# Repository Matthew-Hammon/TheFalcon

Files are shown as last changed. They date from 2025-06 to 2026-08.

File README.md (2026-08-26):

# The Falcon

This is a project that was inspired by ZSA's Moonlander and Voyager split keyboards. I loved how they looked and with my move to a keyboard-driven workflow, I decided that I needed to make the move. I started second-guessing myself when I saw the price, as I was a student, and I came to the realisation that I had the skills to design one.

## Features
* 36 keys per split
* Serial communication between keyboards
* USB2.0 with USB-C connectors
* Voltage protection for hot plugging
* 4 layer PCB
* RGB lighting (see the note)
* QMK compatible
* Compatible with both [Gateron Low Profile 2.0](https://www.gateron.co/products/gateron-low-profile-mechanical-switch-set) (KS-33) and [Gateron G Pro switches](https://www.gateron.co/products/gateron-switch-set)

> [!NOTE]
> I have not been able to get the RGB lighting to work. I have checked the PCB schematic and nothing stands out as the error but I could be wrong. I believe that the problem comes down to the firmware implementation and drivers.

### PCB
The PCB folder contains files for the left and right PCBs separately as well as a panelised version that combines them. The PCBs were designed by me with inspiration from other similar projects. Although four layers increase the production cost, they were intentionally kept to ensure proper signal integrity and return paths, especially due to the fast switching of multiple lines for RGB, PWM and the USB differential pair.

### Case
The SolidWorks folder contains all of the CAD files that I made for the case/switch panel. 
The folders ending with _Threaded are for the initial case designs when I had initial ideas of having the case CNCed. They have threaded pillars used for screwing the bottom plate into the top, with the top also housing the keyboard switches. 
The folders with _ScrewHoles contain a full CAD design for the case, with a bottom case being used along with M2.5 screws and hex standoffs to attach to the switch panel. The switch panel was made using FR-4 and placed alongside the PCB order. Two versions of this were made, one for 'normal' switches and an adjusted one for low-profile switches.

### Parts
All of the parts can be found in the PartsList.xlsx file. The file is detailed and most of the parts have links to places I sourced them from at the time.
A bill of materials for the panel is found as 'bom.xlsx' with the parts positions in 'pos.xlsx'. These were formatted for JLCPCB and at the time they worked. I take no responsibility for anyone who uses them along with the panel for production and I HIGHLY encourage anyone using the files to double-check everything.

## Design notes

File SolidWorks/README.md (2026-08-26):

This folder contains the Switch plate for the left and right keyboards.

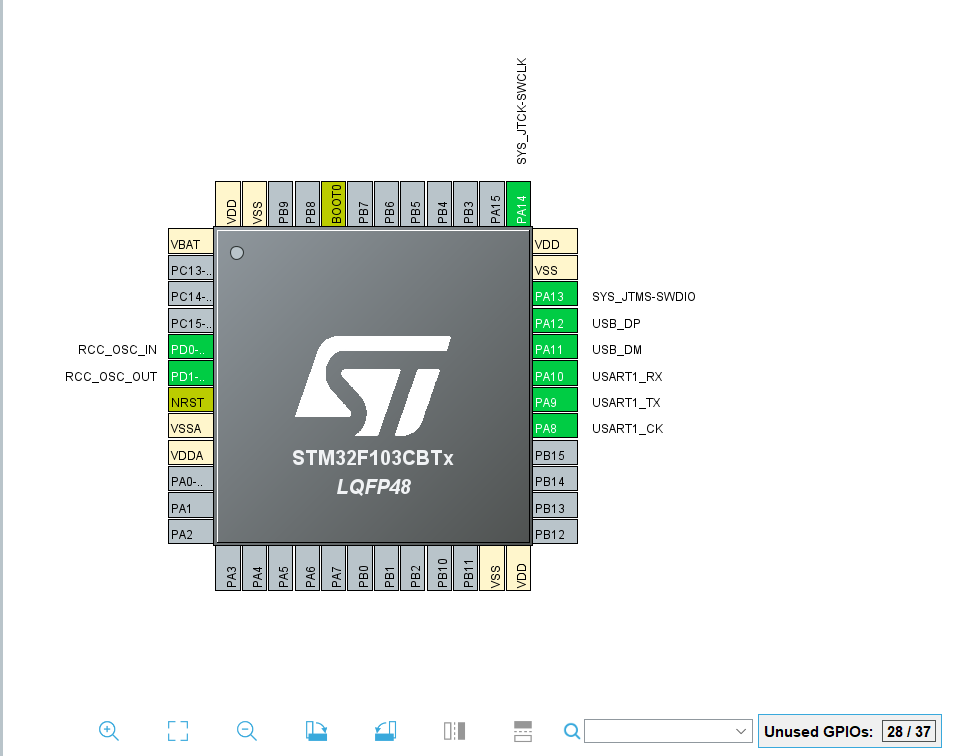
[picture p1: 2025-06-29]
MCU_Pinout.png

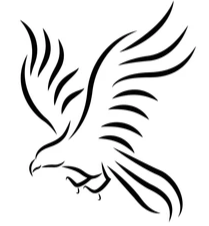
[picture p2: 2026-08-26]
Falcon.png

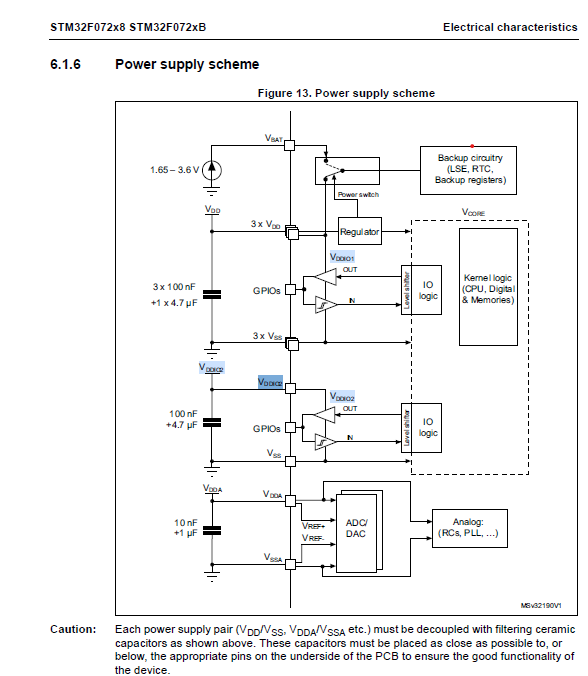
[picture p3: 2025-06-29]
PowerSupplyDecap.png

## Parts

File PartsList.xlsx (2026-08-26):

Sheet: Sheet1
Name | # | Total Number Needed | N/A | Price per unit ($) | Price per unit (R) | Total price for one PCB | Price per double unit | Total price for x units | <- Filtered | Total Price | Filtered Price | Include | Field | Number | Notes
Capacitors | 16 | 160 |  |  | 0.00 | R 0.00 | R 0.00 | R 0.00 | R 0.00 | R 0.00 | R 0.00 | TRUE | Number of PCBS | 5
Diode | 38 | 380 |  |  | 0.00 | R 0.00 | R 0.00 | R 0.00 | R 0.00 | R 0.00 | R 0.00 | TRUE | Number of Units | 3
Resistors | 24 | 240 |  |  | 0.00 | R 0.00 | R 0.00 | R 0.00 | R 0.00 | R 0.00 | R 0.00 | TRUE
FerriteBead | 2 | 20 |  |  | 0.00 | R 0.00 | R 0.00 | R 0.00 | R 0.00 | R 0.00 | R 0.00 | TRUE
RGB Leds | 38 | 380 |  | 0.26 | 4.63 | R 176.06 | R 352.12 | R 1056.37 | R 0.00 | R 1760.62 | R 0.00 | FALSE |  |  | NOT ON JLCPCB
Switches | 38 | 380 |  |  | 0.00 | R 0.00 | R 0.00 | R 0.00 | R 0.00 | R 0.00 | R 0.00 | TRUE
Push Buttons | 3 | 30 |  |  | 0.00 | R 0.00 | R 0.00 | R 0.00 | R 0.00 | R 0.00 | R 0.00 | TRUE
Electrical Switch | 1 | 10 |  |  | 0.00 | R 0.00 | R 0.00 | R 0.00 | R 0.00 | R 0.00 | R 0.00 | TRUE
MCU | 1 | 10 |  | 1.7565 | 31.30 | R 31.30 | R 62.60 | R 187.80 | R 187.80 | R 313.01 | R 313.01 | TRUE
LED Driver | 1 | 10 |  | 0.951 | 16.95 | R 16.95 | R 33.89 | R 101.68 | R 101.68 | R 169.47 | R 169.47 | TRUE
ESD Protection | 2 | 20 |  | 0.0602 | 1.07 | R 2.15 | R 4.29 | R 12.87 | R 12.87 | R 21.46 | R 21.46 | TRUE
Level Converter | 1 | 10 |  | 0.1704 | 3.04 | R 3.04 | R 6.07 | R 18.22 | R 18.22 | R 30.37 | R 30.37 | TRUE
USB Receptical | 2 | 20 |  | 0.0786 | 1.40 | R 2.80 | R 5.60 | R 16.81 | R 16.81 | R 28.01 | R 28.01 | TRUE
Crystal Oscillator | 1 | 10 |  | 0.0665 | 1.19 | R 1.19 | R 2.37 | R 7.11 | R 7.11 | R 11.85 | R 11.85 | TRUE
Total |  |  |  |  |  | R 233.48 | R 466.96 | R 1400.87 | R 344.50 | R 2334.78 | R 574.16
 |  |  |  |  |  |  |  | Price for the
Name | # per single board
Capacitors | 16
Diode | 38
Resistors | 24 | Total Number Needed | Bulk Order | Total Price Bulk Order ($) | Total Price Bulk Order (R) | Total Price
FerriteBead | 2 | 160 |  |  | R 0.00 | R 0.00
RGB Leds | 38 | 380 |  |  | R 0.00 | R 0.00
Switches | 38 | 240 |  |  | R 0.00 | R 0.00
Push Buttons | 3 | 20 |  |  | R 0.00 | R 0.00
Electrical Switch | 1 | 380 | 380.00 | 0.26 | R 4.63 | R 1760.62 |  | NOT ON JLCPCB
MCU | 1 | 380 |  |  | R 0.00 | R 0.00
LED Driver | 1 | 30 |  |  | R 0.00 | R 0.00
ESD Protection | 2 | 10 |  |  | R 0.00 | R 0.00
Level Converter | 1 | 10 | 10.00 | 1.4985 | R 26.70 | R 267.03
USB Receptical | 2 | 10 | 10.00 | 0.795 | R 14.17 | R 141.67
Crystal Oscillator | 1 | 20 | 20.00 | 0.0602 | R 1.07 | R 21.46
 |  | 10 | 10.00 | 0.1704 | R 3.04 | R 30.37
Total |  | 20 | 20.00 | 0.0786 | R 1.40 | R 28.01
 |  | 10 | 10.00 | 0.0665 | R 1.19 | R 11.85
 |  |  |  |  | R 52.20 | R 2261.00

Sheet: Sheet2
Name | # per single board | # per unit | x units | 5 units | Price per component ($) | Price per component (R) | Price per board | Price per unit | Price per x units | Price per 5 units | Include | Fields |  |  | Notes
Capacitors | 16 | 32 | 96 | 160 | 0.1 | 1.786 | R 28.58 | R 57.15 | R 171.46 | R 285.76 | TRUE | x | 3 | X | Just assumed the same prices for all caps, diodes, resistors
Diode | 38 | 76 | 228 | 380 |  | 0 | R 0.00 | R 0.00 | R 0.00 | R 0.00 | TRUE |  |  | X
Resistors | 24 | 48 | 144 | 240 | 0.0022 | 0.039292 | R 0.94 | R 1.89 | R 5.66 | R 9.43 | TRUE |  |  | X
FerriteBead | 2 | 4 | 12 | 20 | 0.2 | 3.572 | R 7.14 | R 14.29 | R 42.86 | R 71.44 | TRUE |  |  | X
RGB Leds | 38 | 76 | 228 | 380 | 0.26 | 4.6436 | R 0.00 | R 0.00 | R 0.00 | R 0.00 | FALSE |  |  |  | Not on JLC PCB
Switches | 38 | 76 | 228 | 380 |  | 0 | R 0.00 | R 0.00 | R 0.00 | R 0.00 | TRUE
Push Buttons | 3 | 6 | 18 | 30 |  | 0 | R 0.00 | R 0.00 | R 0.00 | R 0.00 | TRUE
Electrical Switch | 1 | 2 | 6 | 10 |  | 0 | R 0.00 | R 0.00 | R 0.00 | R 0.00 | TRUE
MCU | 1 | 2 | 6 | 10 | 1.7565 | 31.37109 | R 31.37 | R 62.74 | R 188.23 | R 313.71 | TRUE
LED Driver | 1 | 2 | 6 | 10 | 0.951 | 16.98486 | R 16.98 | R 33.97 | R 101.91 | R 169.85 | TRUE
ESD Protection | 2 | 4 | 12 | 20 | 0.0602 | 1.075172 | R 2.15 | R 4.30 | R 12.90 | R 21.50 | TRUE
Level Converter | 1 | 2 | 6 | 10 | 0.1704 | 3.043344 | R 3.04 | R 6.09 | R 18.26 | R 30.43 | TRUE
USB Receptical | 2 | 4 | 12 | 20 | 0.0786 | 1.403796 | R 2.81 | R 5.62 | R 16.85 | R 28.08 | TRUE
Crystal Oscillator | 1 | 2 | 6 | 10 | 0.0665 | 1.18769 | R 1.19 | R 2.38 | R 7.13 | R 11.88 | TRUE
Connectors | 2 | 4 | 12 | 20 |  | 0 | R 0.00 | R 0.00 | R 0.00 | R 0.00
Total |  |  |  |  |  |  | R 94.21 | R 188.42 | R 565.25 | R 942.08
Name | # per single board | # per unit | x units | 5 units | Price per component ($) | Price per component (R) | Price per board | Price per unit | Price per x units | Price per 5 units | Include | Fields
Capacitors | 16 | 32 | 96 | 160 |  | 0 | R 48.00 | R 96.00 | R 288.00 | R 480.00 | TRUE | x | 3
Diode | 38 | 76 | 228 | 380 |  | 0 | R 114.00 | R 228.00 | R 684.00 | R 1140.00 | TRUE
Resistors | 24 | 48 | 144 | 240 |  | 0 | R 72.00 | R 144.00 | R 432.00 | R 720.00 | TRUE
FerriteBead | 2 | 4 | 12 | 20 |  | 0 | R 6.00 | R 12.00 | R 36.00 | R 60.00 | TRUE
RGB Leds | 38 | 76 | 228 | 380 | 0.26 | 4.6436 | R 114.00 | R 228.00 | R 684.00 | R 1140.00 | TRUE
Switches | 38 | 76 | 228 | 380 |  | 0 | R 114.00 | R 228.00 | R 684.00 | R 1140.00 | TRUE
Push Buttons | 3 | 6 | 18 | 30 |  | 0 | R 9.00 | R 18.00 | R 54.00 | R 90.00 | TRUE
Electrical Switch | 1 | 2 | 6 | 10 |  | 0 | R 3.00 | R 6.00 | R 18.00 | R 30.00 | TRUE
MCU | 1 | 2 | 6 | 10 | 1.7565 | 31.37109 | R 3.00 | R 6.00 | R 18.00 | R 30.00 | TRUE
LED Driver | 1 | 2 | 6 | 10 | 0.951 | 16.98486 | R 3.00 | R 6.00 | R 18.00 | R 30.00 | TRUE
ESD Protection | 2 | 4 | 12 | 20 | 0.0602 | 1.075172 | R 6.00 | R 12.00 | R 36.00 | R 60.00 | TRUE
Level Converter | 1 | 2 | 6 | 10 | 0.1704 | 3.043344 | R 3.00 | R 6.00 | R 18.00 | R 30.00 | TRUE
USB Receptical | 2 | 4 | 12 | 20 | 0.0786 | 1.403796 | R 6.00 | R 12.00 | R 36.00 | R 60.00 | TRUE
Crystal Oscillator | 1 | 2 | 6 | 10 | 0.0665 | 1.18769 | R 3.00 | R 6.00 | R 18.00 | R 30.00 | TRUE
Connectors
Total |  |  |  |  |  |  | R 504.00 | R 1008.00 | R 3024.00 | R 5040.00

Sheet: JLCPCB(Detailed)
Name | Value | # per single board | # per unit | x units | 5 units | Price per component ($) | Price per component (R) | Price per board | Price per unit | Price per x units | Price per 5 units | Include | Package | Fields |  | Link | Notes |  | In Order
Capacitors | 10u | 1 | 2 | 6 | 10 | 0.0087 | 0.155382 | R 0.16 | R 0.31 | R 0.93 | R 1.55 | TRUE | 0805 | x | 3 | https://jlcpcb.com/partdetail/2065-CL21A106KOQNNNE/C1713 |  |  | TRUE
 | 100n | 8 | 16 | 48 | 80 | 0.0032 | 0.057152 | R 0.46 | R 0.91 | R 2.74 | R 4.57 | TRUE | 0402 |  |  | https://jlcpcb.com/partdetail/1877-CL05B104KO5NNNC/C1525 |  |  | TRUE
 | 10n | 1 | 2 | 6 | 10 | 0.0031 | 0.055366 | R 0.06 | R 0.11 | R 0.33 | R 0.55 | TRUE | 0402 |  |  | https://jlcpcb.com/partdetail/1876-0402B103K500NT/C1524 |  |  | TRUE
 | 1u | 3 | 6 | 18 | 30 | 0.0032 | 0.057152 | R 0.17 | R 0.34 | R 1.03 | R 1.71 | TRUE | 0603 |  |  | https://jlcpcb.com/partdetail/1944-CL10A105KO8NNNC/C1592 |  |  | TRUE
 | 22u | 2 | 4 | 12 | 20 | 0.0324 | 0.578664 | R 1.16 | R 2.31 | R 6.94 | R 11.57 | TRUE | 1206 |  |  | https://jlcpcb.com/partdetail/2211-1206X226K100NT/C1859 |  |  | TRUE
 | 10p | 2 | 4 | 12 | 20 | 0.001 | 0.01786 | R 0.04 | R 0.07 | R 0.21 | R 0.36 | TRUE | 0402 |  |  | https://jlcpcb.com/partdetail/1897-0402CG100J500NT/C1545 |  |  | TRUE
 |  | 17
Resistors | 5,1k | 4 | 8 | 24 | 40 | 0.001 | 0.01786 | R 0.07 | R 0.14 | R 0.43 | R 0.71 | TRUE | 0603 |  |  | https://jlcpcb.com/partdetail/23794-0603WAF5111T5E/C23067 | 100mW |  | TRUE
 | 100k | 1 | 2 | 6 | 10 | 0.001 | 0.01786 | R 0.02 | R 0.04 | R 0.11 | R 0.18 | TRUE | 0603 |  |  | https://jlcpcb.com/partdetail/Yageo-RC0603FR07100KL/C14675 | 100mW |  | TRUE
 | 10k | 1 | 2 | 6 | 10 | 0.0008 | 0.014288 | R 0.01 | R 0.03 | R 0.09 | R 0.14 | TRUE | 0603 |  |  | https://jlcpcb.com/partdetail/16079-0603WAJ0103T5E/C15401 | 100mW |  | TRUE
 | 4k7 | 2 | 4 | 12 | 20 | 0.0011 | 0.019646 | R 0.04 | R 0.08 | R 0.24 | R 0.39 | TRUE | 0603 |  |  | https://jlcpcb.com/partdetail/23889-0603WAF4701T5E/C23162 | Maybe change to 4.7k for I2C |  | TRUE
 | 20 | 10 | 20 | 60 | 100 | 0.01 | 0.1786 | R 1.79 | R 3.57 | R 10.72 | R 17.86 | TRUE | 0603 |  |  | https://jlcpcb.com/partdetail/23677-0603WAF200JT5E/C22950 |  |  | TRUE
 | 51 | 5 | 10 | 30 | 50 | 0.01 | 0.1786 | R 0.89 | R 1.79 | R 5.36 | R 8.93 | TRUE | 0603 |  |  | https://jlcpcb.com/partdetail/18426-UNI_ROYAL0805W8F510JT5E/C17738 |  |  | TRUE
 | 1k5 | 1 | 2 | 6 | 10 | 0.01 | 0.1786 | R 0.18 | R 0.36 | R 1.07 | R 1.79 | TRUE | 0603 |  |  | https://jlcpcb.com/partdetail/23570-0603WAF1501T5E/C22843 |  |  | TRUE
 | 0 | 1 | 2 | 6 | 10 | 0.0016 | 0.028576 | R 0.03 | R 0.06 | R 0.17 | R 0.29 | TRUE | 0805 |  |  | https://jlcpcb.com/partdetail/18165-0805W8F0000T5E/C17477 |  |  | TRUE
 |  | 25
Diode | x | 38 | 76 | 228 | 380 | 0.009 | 0.16074 | R 6.11 | R 12.22 | R 36.65 | R 61.08 | TRUE | SOD-123 |  |  | https://jlcpcb.com/partdetail/2456-1N4148W/C2099 |  |  | TRUE
PWR LED | x | 1 | 2 | 6 | 10 | 0.02 | 0.3572 | R 0.36 | R 0.71 | R 2.14 | R 3.57 | TRUE | 0805 |  |  | https://jlcpcb.com/partdetail/85429-NCD0805G1/C84260 |  |  | TRUE
Fuse | 500mA | 1 | 2 | 6 | 10 | 0.0512 | 0.914432 | R 0.91 | R 1.83 | R 5.49 | R 9.14 | TRUE | 1206 |  |  | https://jlcpcb.com/partdetail/Shenzhen_JdtFuse-ASMD1206025/C135336 |  |  | TRUE
RGB Drivers | IS31FL3729 | 1 | 2 | 6 | 10 | 0.951 | 16.98486 | R 16.98 | R 33.97 | R 101.91 | R 169.85 | TRUE | QFN-32-EP(4x4) |  |  | https://jlcpcb.com/partdetail/3305932-IS31FL3729_QFLS4TR/C2940549 |  |  | TRUE
Conn | 01x04 | 2 | 4 | 12 | 20 | 0.0585 | 1.04481 | R 0.00 | R 0.00 | R 0.00 | R 0.00 | FALSE | HAVENT INCLUDED YET |  |  | https://jlcpcb.com/partdetail/XFCN-PM254V_11_04H85/C541851
 | 01x01 | 1 | 2 | 6 | 10 |  | 0 | R 0.00 | R 0.00 | R 0.00 | R 0.00 | FALSE | Just solder pad
 | 02x05 | 1 | 2 | 6 | 10 |  | 0 | R 0.00 | R 0.00 | R 0.00 | R 0.00 | TRUE |  |  |  |  | SMALLER: | https://jlcpcb.com/partdetail/Megastar-ZX_PM1_27_25PU/C7499360
RGB Leds | T36K3BGR | 38 | 76 | 228 | 380 | 0.0365 | 0.65189 | R 24.77 | R 49.54 | R 148.63 | R 247.72 | TRUE |  |  |  | https://jlcpcb.com/partdetail/Hongqiguang-T36K3BGR05D000121U1930/C5184580 | Not on JLC PCB |  | FALSE
Gateron Switches | x | 38 | 76 | 228 | 380 |  | 0 | R 0.00 | R 0.00 | R 0.00 | R 0.00 | FALSE |  |  |  |  |  |  | TRUE
Push Button | x | 2 | 4 | 12 | 20 | 0.15 | 2.679 | R 5.36 | R 10.72 | R 32.15 | R 53.58 | TRUE | SMD,2.5x3mm |  |  | https://jlcpcb.com/partdetail/OmronElectronics-B3U1000P/C231329 |  |  | TRUE
STM32 | x | 1 | 2 | 6 | 10 | 3.1725 | 56.66085 | R 56.66 | R 113.32 | R 339.97 | R 566.61 | TRUE |  |  |  | https://jlcpcb.com/partdetail/Stmicroelectronics-STM32G431CBT6/C529355 |  |  | TRUE
USB Connector | x | 2 | 4 | 12 | 20 | 0.0786 | 1.403796 | R 2.81 | R 5.62 | R 16.85 | R 28.08 | TRUE |  |  |  | https://jlcpcb.com/partdetail/gswitch-GT_USB7010ASV/C2988369 |  |  | TRUE
Level Converter | x | 1 | 2 | 6 | 10 | 0.1704 | 3.043344 | R 3.04 | R 6.09 | R 18.26 | R 30.43 | TRUE |  |  |  | https://jlcpcb.com/partdetail/Advanced_MonolithicSystems-AMS1117_33/C6186 |  |  | TRUE
ESD Converter | USBLC6-2P6 | 2 | 4 | 12 | 20 | 0.0602 | 1.075172 | R 2.15 | R 4.30 | R 12.90 | R 21.50 | TRUE |  |  |  | https://jlcpcb.com/partdetail/31512546-USBLC6_2P6_UMW/C29780639 |  |  | TRUE
Crystal Oscillator | x | 1 | 2 | 6 | 10 | 0.0665 | 1.18769 | R 1.19 | R 2.38 | R 7.13 | R 11.88 | TRUE |  |  |  | https://jlcpcb.com/partdetail/Yxc_CrystalOscillators-X322516MOB4SI/C12668 |  |  | TRUE
Mounting Hole | x | 6 | 12 | 36 | 60 |  | 0 | R 0.00 | R 0.00 | R 0.00 | R 0.00 | TRUE
Switch Socket |  | 0 | 0 | 0 | 0 | 0.1342777778 | 2.398201111 | R 0.00 | R 0.00 | R 0.00 | R 0.00 | FALSE
DIP Switch | 2 pin | 0 | 0 | 0 | 0 | 0.2513 | 4.488218 | R 0.00 | R 0.00 | R 0.00 | R 0.00 | TRUE |  |  |  | https://jlcpcb.com/partdetail/41719-DSHP02TSGET/C40735 |  |  | FALSE
 |  | 178 |  |  |  |  |  | R 125.41 | R 250.81 | R 752.43 | R 1254.06
M2.5 Standoff | https://www.digikey.co.za/en/products/detail/würth-elektronik/970080144/9488538 |  |  |  |  |  |  |  |  | https://za.rs-online.com/web/p/standoffs/2053013?gb=s
Gaskets | https://za.rs-online.com/web/p/foam-tapes/0567963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
NEED TO DO CONNECTORS
M2 Standoff | https://za.rs-online.com/web/p/standoffs/2240361?gb=s
M2 Screw | https://www.robotics.org.za/M2-L8-KIT
Rubber feet | https://za.rs-online.com/web/p/anti-slip-pads/1735972
PCB | 2 LAYER
 | 4 LAYER | 900
Final
M2.5x5mm Standoff | https://za.rs-online.com/web/p/standoffs/2052903 |  |  |  |  |  | R 9.58 |  | 15
M2.5x8mm Standoff | https://za.rs-online.com/web/p/standoffs/2052905?gb=s |  |  |  |  |  | R 11.04 |  | 30 | R 331.23
M2.5 Screw | https://za.rs-online.com/web/p/machine-screws/9141630?gb=s |  |  |  |  |  | R 0.98 |  | 100 | R 97.70
M2.5 Insert |  |  |  |  |  |  |  |  |  | R 0.00
Rubber feet | https://za.rs-online.com/web/p/anti-slip-pads/1735972 |  |  |  |  |  | R 273.99 | Set - 150 | 1 | R 273.99 |  |  | https://www.digikey.co.za/en/products/detail/3m/SJ5302/2345107
Gasket | https://za.rs-online.com/web/p/foam-tapes/0567963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 |  |  |  |  |  | 157.58 | Set | 1 | R 157.58
Foam Layer | https://za.rs-online.com/web/p/foam-inserts/1368892?gb=s |  |  |  |  |  | 76.98 |  | 2 | R 153.96
RGB Leds | https://www.digikey.co.za/en/products/detail/harvatek-corporation/T36K3BGR-05D000121U1930/13588739
 |  |  |  |  |  |  |  |  |  | R 1014.46

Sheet: Sheet3
 | Cost per unit
PCB | R 560.00
Switch layer | R 100.00
RGB Leds | R 330.00
Switches |  | Approx, depends on switch
Key caps |  | Estimated but depends
Screws and mounts | R 150.00
Feet | R 23.00
 | R 1163.00

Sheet: Left
Comment | Designator | Footprint | LCSC Part Number | Extended | New Part Number | LCSC Part Number
10n | C6 | Capacitor_SMD:C_0402_1005Metric | C1524 | TRUE | C15195 | C15195
100n | C2,C3,C4,C5,C8,C9,C12,C14 | Capacitor_SMD:C_0402_1005Metric | C1525 | FALSE |  | C1525
10p | C15,C16 | Capacitor_SMD:C_0402_1005Metric | C1545 | TRUE | C32949 | C32949
1u | C7,C13,C17 | Capacitor_SMD:C_0603_1608Metric | C1592 | TRUE | C15849 | C15849
10u | C1 | Capacitor_SMD:C_0805_2012Metric | C1713 | TRUE | C15850 | C15850
22u | C10,C11 | Capacitor_SMD:C_1206_3216Metric | C1859 | TRUE | C12891 | C12891
Diode | D1,D2,D3,D4,D5,D6,D7,D8,D9,D10,D11,D12,D13,D14,D15,D16,D17,D18,D19,D20,D21,D22,D23,D24,D25,D26,D27,D28,D29,D30,D31,D32,D33,D36,D37,D38 | Diode_SMD:D_SOD-123 | C2099 | TRUE | C81598 | C81598
AMS1117-3.3 | U4 | Package_TO_SOT_SMD:SOT-223-3_TabPin2 | C6186 | FALSE |  | C6186
X322516MOB4SI | Y1 | SamacSys_Parts:X322516MOB4SI | C12668 | FALSE |  | C12668
100k | R5 | Resistor_SMD:R_0603_1608Metric | C14675 | TRUE | C25803 | C25803
10k | R6 | Resistor_SMD:R_0603_1608Metric | C15401 | TRUE | C25804 | C25804
51 | R11,R13,R16,R19,R22 | Resistor_SMD:R_0603_1608Metric | C17738 | FALSE |  | C17738
1k5 | R25 | Resistor_SMD:R_0603_1608Metric | C22843 | FALSE |  | C22843
20 | R9,R10,R12,R14,R15,R17,R18,R20,R21,R23 | Resistor_SMD:R_0603_1608Metric | C22950 | FALSE |  | C22950
5k1 | R1,R2,R3,R4 | Resistor_SMD:R_0603_1608Metric | C23067 | TRUE | C23186 | C23186
4k7 | R24,R33 | Resistor_SMD:R_0603_1608Metric | C23162 | FALSE |  | C23162
LED | D39 | LED_SMD:LED_0805_2012Metric | C84260 | TRUE | C84256 | C84256
500mA | F1 | Fuse:Fuse_1206_3216Metric | C135336 | TRUE | C20798 | C20798 | No Stock of 1
SW_Push | SW1,SW2 | Button_Switch_SMD:SW_SPST_B3U-1000P | C231329 | TRUE | C720477 | C720477
STM32G431CBTx | U6 | Package_QFP:LQFP-48_7x7mm_P0.5mm | C529355 | FALSE |  | C529355
IS31FL3729-QFLS4-TR | IC1 | SamacSys_Parts:QFN40P400X400X80-33N-D | C2940549 | FALSE |  | C2940549
USB_C_Receptacle_USB2.0_16P | USB1,USB2 | Connector_USB:USB_C_Receptacle_G-Switch_GT-USB-7010ASV | C2988369 | FALSE |  | C2988369
USBLC6-2P6 | U2,U3 | Package_TO_SOT_SMD:SOT-666 | C29780639 | FALSE |  | C29780639

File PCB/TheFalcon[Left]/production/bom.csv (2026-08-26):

Designator | Footprint | Quantity | Value | LCSC Part #
C1 | 0805 | 1 | 10u
C10, C11 | 1206 | 2 | 22u
C12, C14, C2, C3, C4, C5, C8, C9 | 0402 | 8 | 100n
C13, C17, C7 | 0603 | 3 | 1u
C15, C16 | 0402 | 2 | 10p
C6 | 0402 | 1 | 10n
D1, D10, D11, D12, D13, D14, D15, D16, D17, D18, D19, D2, D20, D21, D22, D23, D24, D25, D26, D27, D28, D29, D3, D30, D31, D32, D33, D36, D37, D38, D4, D5, D6, D7, D8, D9 | D_SOD-123 | 36 | Diode
D39 | 0805 | 1 | LED
F1 | 1206 | 1 | 500mA
IC1 | QFN40P400X400X80-33N-D | 1 | IS31FL3729-QFLS4-TR
J1, J3, J4, J5, J6, J7 | SolderWire-0.1sqmm_1x01_D0.4mm_OD1mm | 6 | Conn_01x01
J2 | SolderWire-1sqmm_1x04_P5.4mm_D1.4mm_OD2.7mm | 1 | Conn_01x04_Pin
R1, R2, R3, R4 | 0603 | 4 | 5k1
R10, R12, R14, R15, R17, R18, R20, R21, R23, R9 | 0603 | 10 | 20
R11, R13, R16, R19, R22 | 0603 | 5 | 51
R24, R33 | 0603 | 2 | 4k7
R25 | 0603 | 1 | 1k5
R5 | 0603 | 1 | 100k
R6 | 0603 | 1 | 10k
RGB1, RGB10, RGB11, RGB12, RGB13, RGB14, RGB15, RGB16, RGB17, RGB18, RGB19, RGB2, RGB20, RGB21, RGB22, RGB23, RGB24, RGB25, RGB26, RGB27, RGB28, RGB29, RGB3, RGB30, RGB31, RGB32, RGB33, RGB34, RGB35, RGB37, RGB4, RGB5, RGB6, RGB7, RGB8, RGB9 | T36K3BGR05D000121U1930_MODEL_INVERTED | 36 | T36K3BGR-05D000121U1930
S1, S10, S11, S12, S13, S14, S15, S16, S17, S18, S19, S2, S20, S21, S22, S23, S24, S25, S26, S27, S28, S29, S3, S30, S31, S32, S33, S34, S4, S5, S6, S7, S8, S9 | MX_KS33-Solderable-1U | 34 | Keyswitch
S35, S36 | MX_KS33-Solderable-1.5U-Vertical | 2 | Keyswitch
SW1, SW2 | SW_SPST_B3U-1000P | 2 | SW_Push
U2, U3 | SOT-666 | 2 | USBLC6-2P6
U4 | SOT-223-3_TabPin2 | 1 | AMS1117-3.3
U6 | LQFP-48_7x7mm_P0.5mm | 1 | STM32G431CBTx
USB1, USB2 | USB_C_Receptacle_G-Switch_GT-USB-7010ASV | 2 | USB_C_Receptacle_USB2.0_16P
Y1 | X322516MOB4SI | 1 | X322516MOB4SI

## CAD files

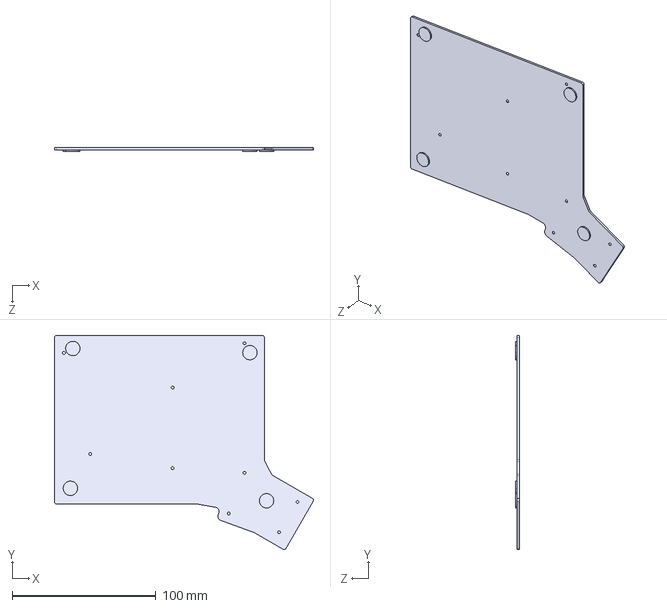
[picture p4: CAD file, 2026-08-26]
BottomPlate_Left.STEP
179.9 x 148.7 x 2.50 mm

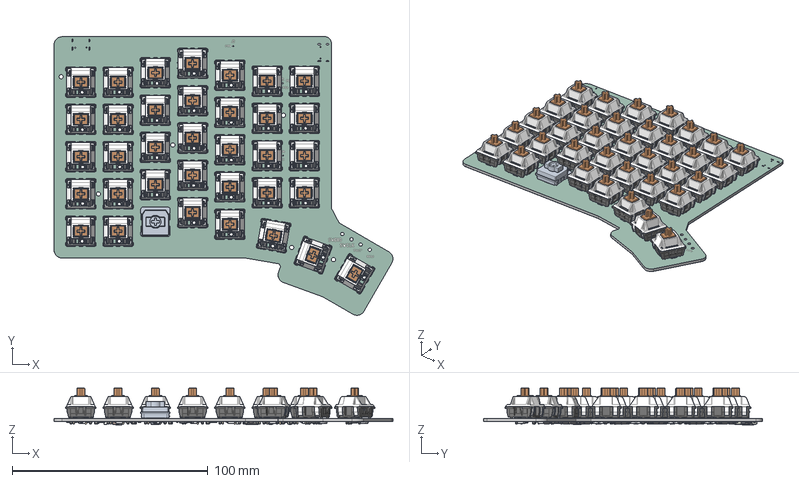
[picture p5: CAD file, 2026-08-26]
PCB/TheFalcon[Left]/TheFalcon[Left].step
173.3 x 142.5 x 18.8 mm
T36K3BGR-05D000121U1930 x 36
MX_PCB x 35
TheFalcon[Left] 1.23.1
D_SOD-123 x 35
LQFP-48_7x7mm_P0.5mm
ThermalPin
PinsArrayLR
PinsArrayTB
C_0603_1608Metric x 3
LED_0805_2012Metric
C_0402_1005Metric x 11
SOT-666 x 2
R_0603_1608Metric x 24
C_0805_2012Metric
Pins
TheFalcon[Left] 1.114.1
SW_SPST_B3U-1000P x 2
C_1206_3216Metric x 2
Fuse_1206_3216Metric
SOT-223
TheFalcon[Left]_silkscreen
TheFalcon[Left]_soldermask
TheFalcon[Left]_PCB

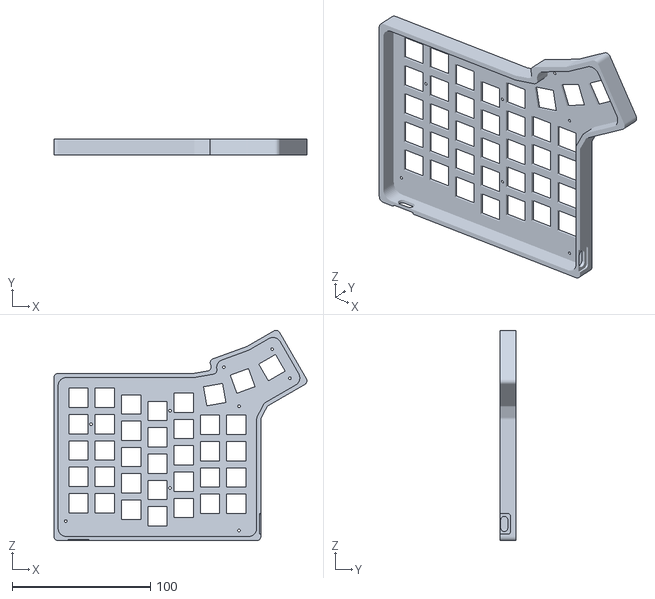
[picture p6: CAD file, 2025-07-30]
SolidWorks/Left_Threaded/3DPrint/SwitchLayer.STL
183.2 x 11.5 x 152.4

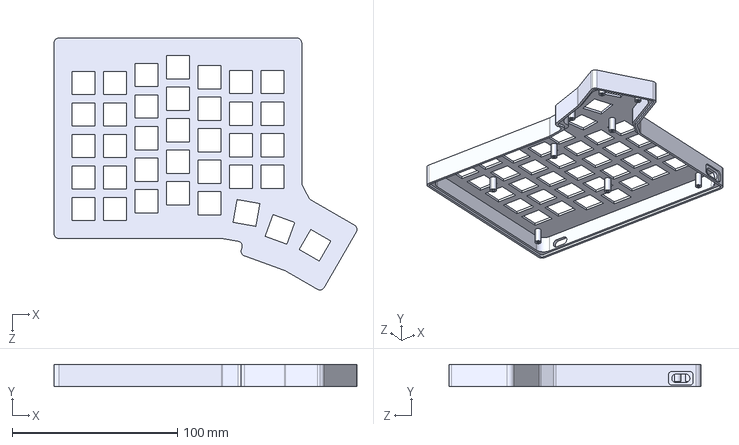
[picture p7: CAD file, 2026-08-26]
SolidWorks/Left_Threaded/Production/SwitchLayer_Left.STEP
183.2 x 13.5 x 152.4 mm

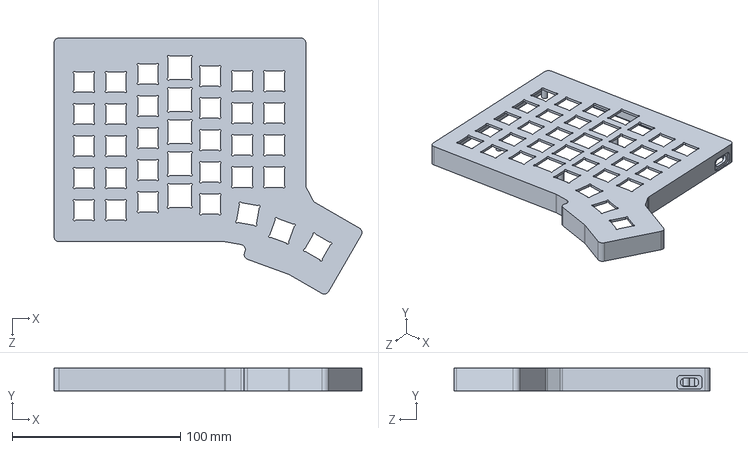
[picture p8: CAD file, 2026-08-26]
SolidWorks/Left_Threaded/SwitchLayer_Left.SLDPRT
183.2 x 13.5 x 152.4 mm

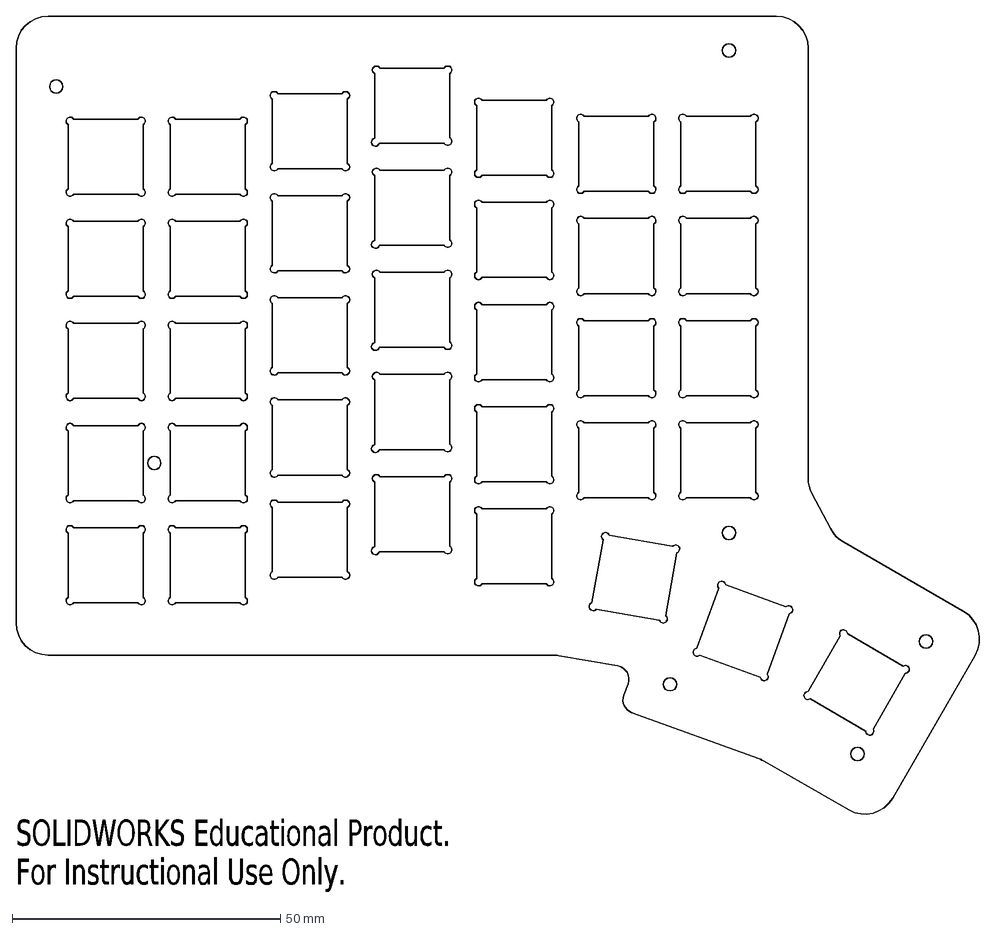
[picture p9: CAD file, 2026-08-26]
SolidWorks/SwitchPlate/Left/SwitchLayer_Left.DXF
SOLIDWORKS Educational Product.
For Instructional Use Only.

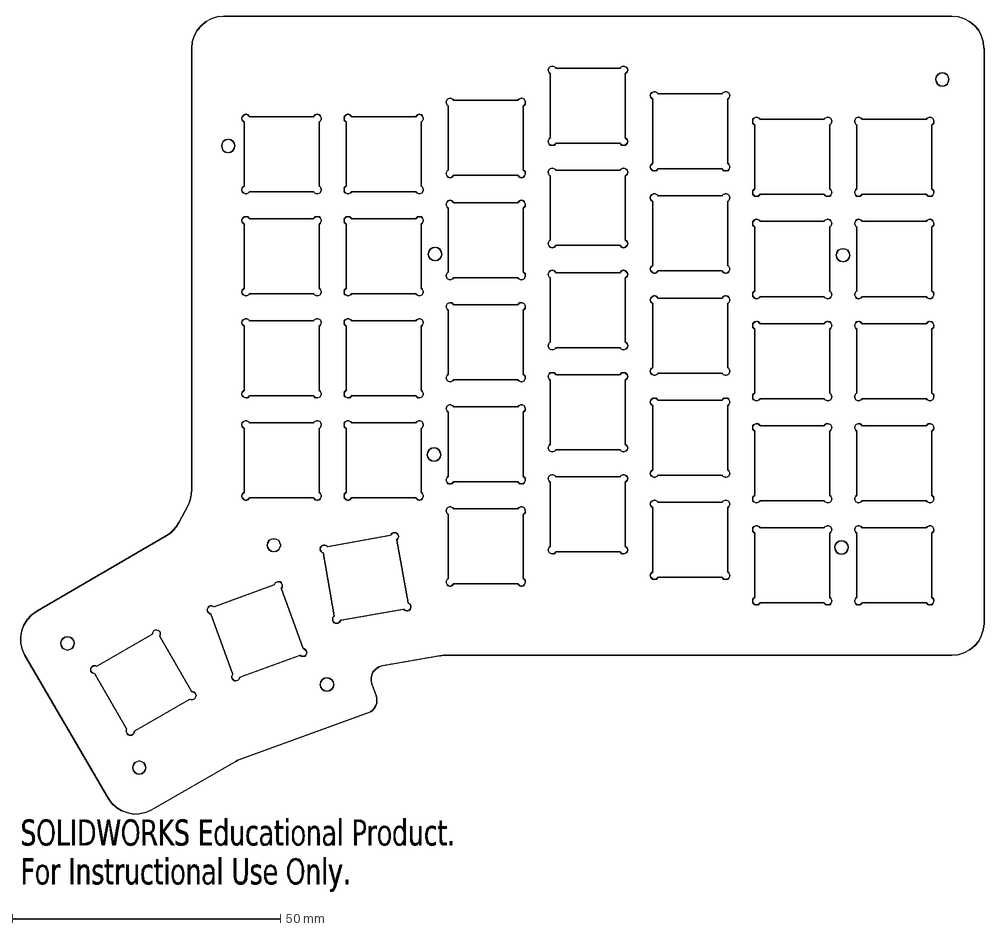
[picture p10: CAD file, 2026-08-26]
SolidWorks/SwitchPlate/Right/SwitchLayer_Right.DXF
SOLIDWORKS Educational Product.
For Instructional Use Only.

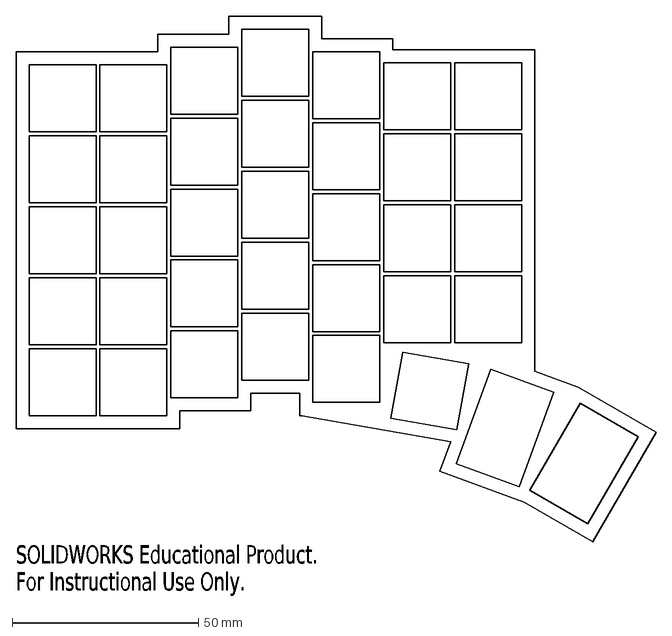
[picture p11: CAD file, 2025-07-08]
PCB/TheFalcon[Left]/p25uLeftSpecial.DXF
SOLIDWORKS Educational Product.
For Instructional Use Only.

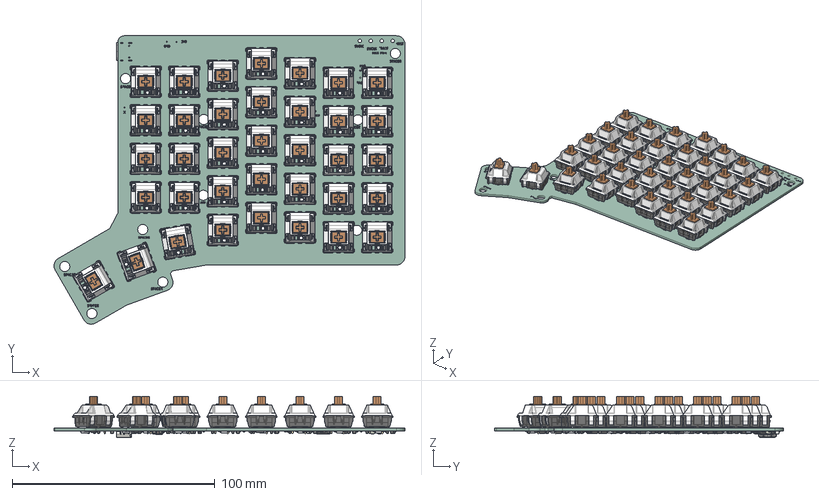
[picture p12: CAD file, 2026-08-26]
SolidWorks/Right_Threaded/TheFalcon[Right].step
173.3 x 142.5 x 20.4 mm
MX_PCB x 36
T36K3BGR-05D000121U1930 x 36
D_SOD-123 x 35
ThermalPin
PinsArrayLR
PinsArrayTB
C_0402_1005Metric x 11
R_0603_1608Metric x 23
C_0603_1608Metric x 3
LQFP-48_7x7mm_P0.5mm
SW_SPST_B3U-1000P x 2
Fuse_1206_3216Metric
USB_C_Receptacle_GCT_USB4105-xx-A_16P_TopMnt_Horizontal
C_0805_2012Metric
Pins
TheFalcon[Right] 1.115.1
LED_0805_2012Metric
C_1206_3216Metric x 2
SOT-666
SOT-223
TheFalcon[Right]_silkscreen
TheFalcon[Right]_PCB

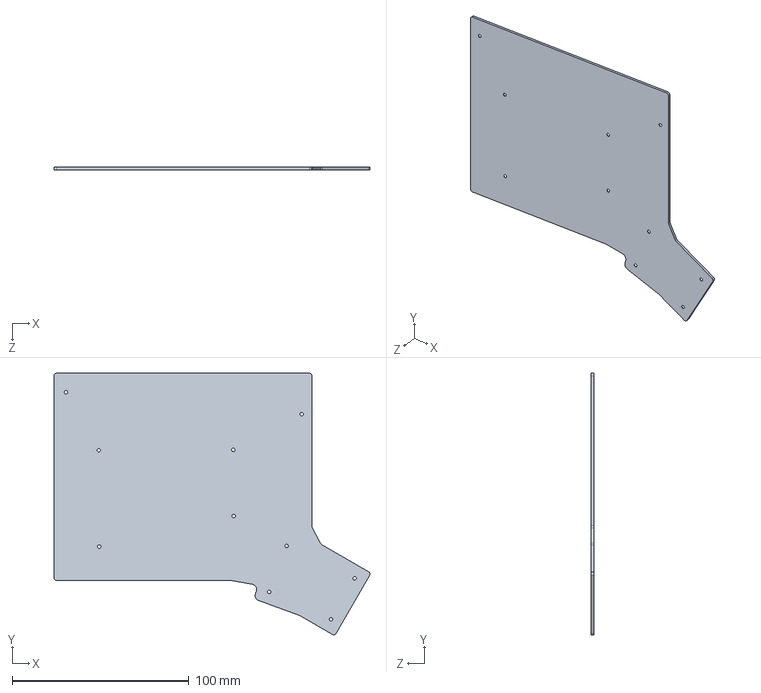
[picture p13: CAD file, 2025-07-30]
SolidWorks/Right_Threaded/BottomPlate_Right.SLDPRT
178.6 x 147.9 x 1.50 mm

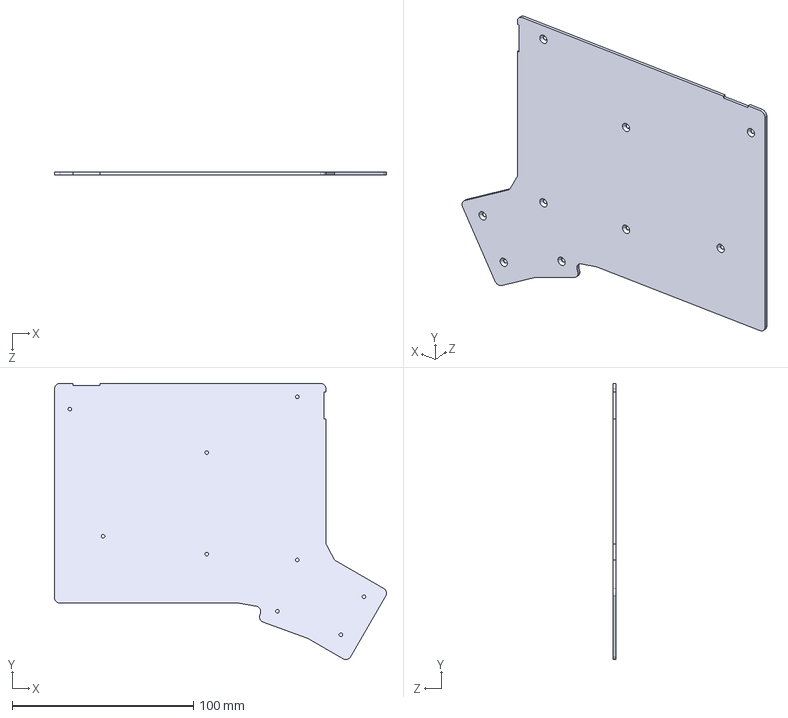
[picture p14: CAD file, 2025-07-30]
SolidWorks/Left_Threaded/Production/BottomPlate.STEP
183.2 x 152.4 x 1.50 mm

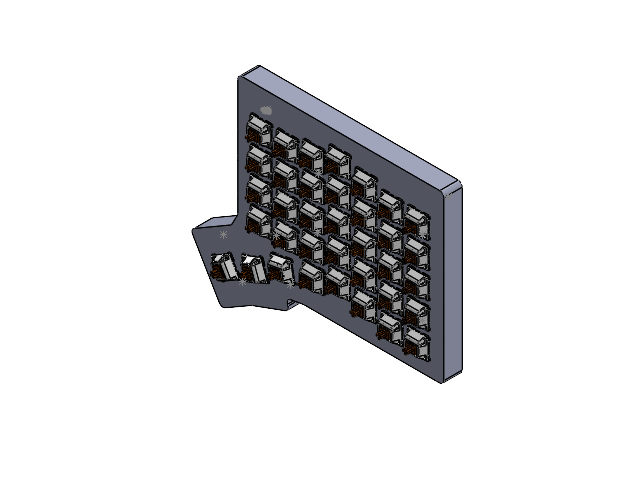
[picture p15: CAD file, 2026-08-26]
SolidWorks/Right_Threaded/RightSideCase.SLDASM
Body.step
ThermalPin.step
PinsArrayLR.step
PinsArrayTB.step
Body-0.step
Pins.step
TheFalcon[Right] 1.115.1.step
MX_PCB.step x 36
T36K3BGR-05D000121U1930.step x 36
D_SOD-123.step x 35
C_0402_1005Metric.step x 11
R_0603_1608Metric.step x 23
C_0603_1608Metric.step x 3
LQFP-48_7x7mm_P0.5mm.step
SW_SPST_B3U-1000P.step x 2
Fuse_1206_3216Metric.step
USB_C_Receptacle_GCT_USB4105-xx-A_16P_TopMnt_Horizontal.step
C_0805_2012Metric.step
LED_0805_2012Metric.step
C_1206_3216Metric.step x 2
SOT-666.step
SOT-223.step
TheFalcon[Right]_silkscreen.step
TheFalcon[Right]_PCB.step
SwitchLayer_Right
BottomPlate_Right

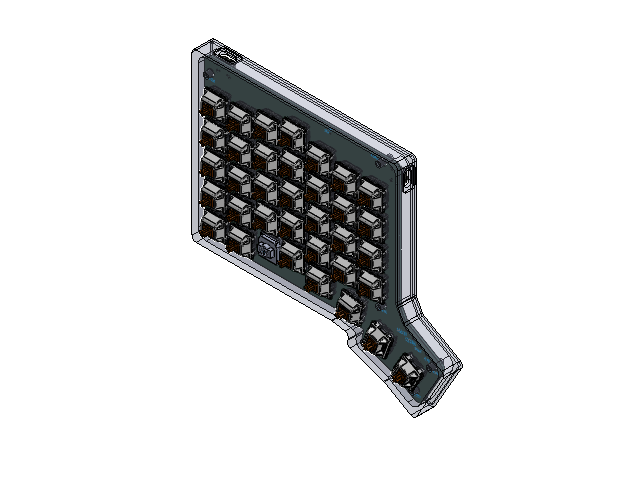
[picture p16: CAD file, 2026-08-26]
SolidWorks/Left_Threaded/LeftSideCase.SLDASM
TheFalcon[Left] 1.23.1.step
Body.step
ThermalPin.step
PinsArrayLR.step
PinsArrayTB.step
Body-0.step
Pins.step
TheFalcon[Right] 1.115.1.step
T36K3BGR-05D000121U1930.step x 36
MX_PCB.step x 35
D_SOD-123.step x 35
LQFP-48_7x7mm_P0.5mm.step
C_0603_1608Metric.step x 3
LED_0805_2012Metric.step
C_0402_1005Metric.step x 11
SOT-666.step x 2
R_0603_1608Metric.step x 24
C_0805_2012Metric.step
USB_C_Receptacle_GCT_USB4105-xx-A_16P_TopMnt_Horizontal.step x 2
SW_SPST_B3U-1000P.step x 2
C_1206_3216Metric.step x 2
Fuse_1206_3216Metric.step
SOT-223.step
TheFalcon[Left]_silkscreen.step
TheFalcon[Left]_PCB.step
SwitchLayer_Left

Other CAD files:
SolidWorks/Left_Threaded/BottomPlate_Left.SLDPRT
SolidWorks/Left_Threaded/Production/SwitchLayerUpdated.STEP
SwitchLayer_Left.STEP
SolidWorks/Left_Threaded/Production/BottomPlate_Left.STEP
SolidWorks/Left_ScrewHoles/BottomPlate_Left.SLDPRT
SolidWorks/Left_ScrewHoles/LeftSideCase.SLDASM
SolidWorks/Left_ScrewHoles/SwitchLayer_Left.SLDPRT
SolidWorks/Left_ScrewHoles/SwitchLayer_Left.STEP
SolidWorks/Left_ScrewHoles/TheFalcon[Left].step
SolidWorks/Left_ScrewHoles_LowProfile/3DPrint/BottomPlate_Left.STL
SolidWorks/Left_ScrewHoles_LowProfile/3DPrint/SwitchLayer_Left.STEP
SolidWorks/Left_ScrewHoles_LowProfile/3DPrint/SwitchLayer_Left.STL
SolidWorks/Left_ScrewHoles_LowProfile/BottomPlate_Left.SLDPRT
SolidWorks/Left_ScrewHoles_LowProfile/LeftSideCase.SLDASM
SolidWorks/Left_ScrewHoles_LowProfile/Production/BottomPlate_Left.STEP
SolidWorks/Left_ScrewHoles_LowProfile/Production/SwitchLayer.STEP
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

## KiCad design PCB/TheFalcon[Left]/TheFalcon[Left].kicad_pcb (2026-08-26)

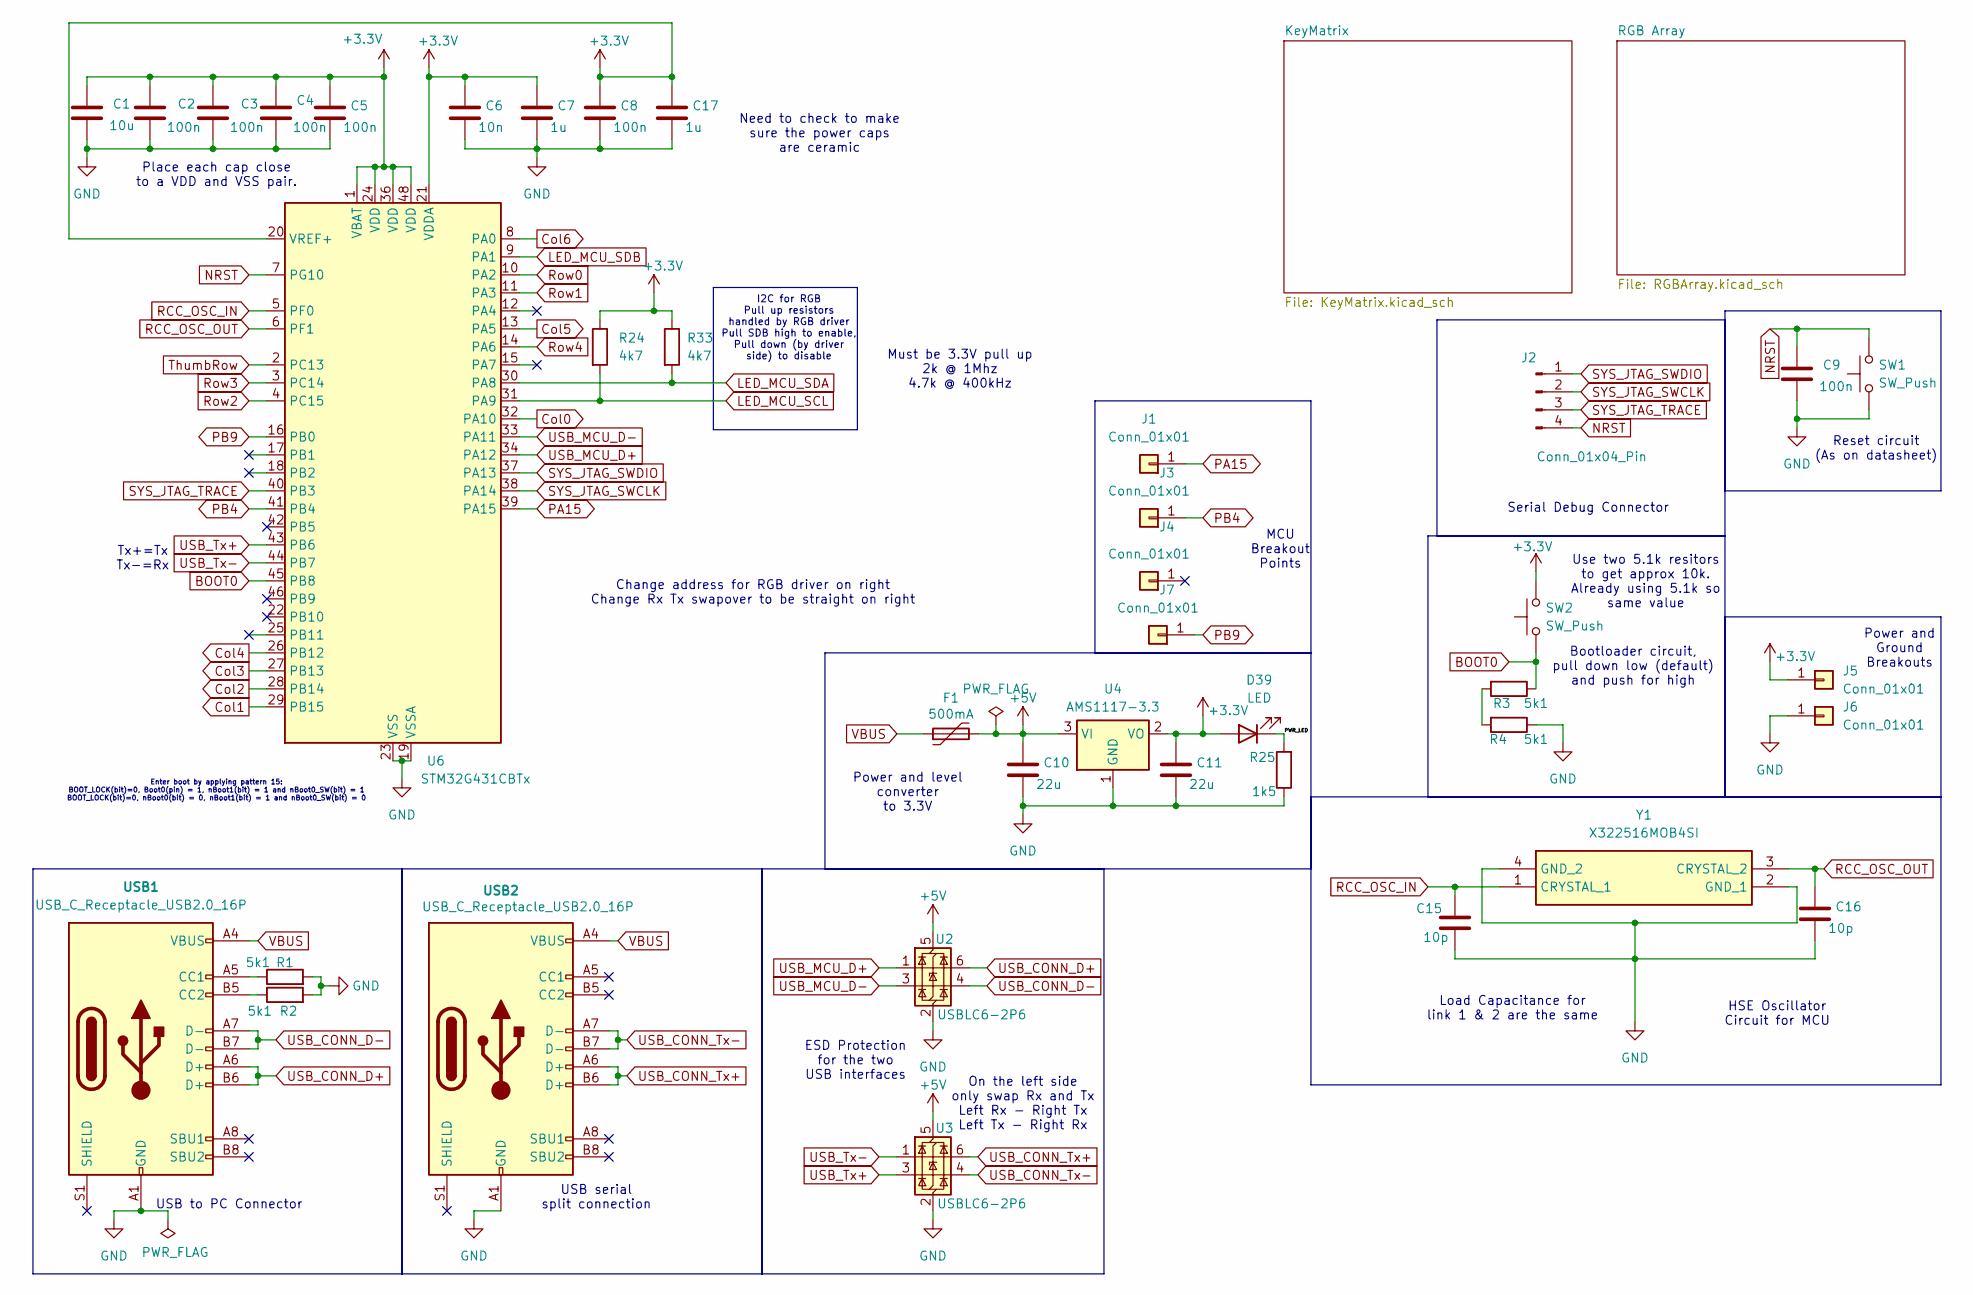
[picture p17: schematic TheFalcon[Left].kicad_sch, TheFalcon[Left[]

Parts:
C1: 10u; C_0805_2012Metric; LCSC Part Number C1713
C2, C3, C4, C5, C8, C9: 100n; C_0402_1005Metric; LCSC Part Number C1525
C6: 10n; C_0402_1005Metric; LCSC Part Number C1524
C7, C17: 1u; C_0603_1608Metric; LCSC Part Number C1592
C10, C11: 22u; C_1206_3216Metric; LCSC Part Number C1859
C15, C16: 10p; C_0402_1005Metric; LCSC Part Number C1545
D39: LED; LED_0805_2012Metric; LCSC Part Number C84260
F1: 500mA; Fuse_1206_3216Metric; LCSC Part Number C135336
J1, J3, J4, J5, J6, J7: Conn_01x01; SolderWire-0.1sqmm_1x01_D0.4mm_OD1mm
J2: Conn_01x04_Pin; SolderWire-1sqmm_1x04_P5.4mm_D1.4mm_OD2.7mm
R1, R2, R3, R4: 5k1; R_0603_1608Metric; LCSC Part Number C23067
R24, R33: 4k7; R_0603_1608Metric; LCSC Part Number C23162
R25: 1k5; R_0603_1608Metric; LCSC Part Number C22843
SW1, SW2: SW_Push; SPDT_Switch_KiCad_BasicComponent; LCSC Part Number C231329
U2, U3: USBLC6-2P6; SOT-666; LCSC Part Number C29780639
U4: AMS1117-3.3; SOT-223-3_TabPin2; LCSC Part Number C6186
U6: STM32G431CBTx; LQFP-48_7x7mm_P0.5mm; LCSC Part Number C529355
USB1, USB2: USB_C_Receptacle_USB2.0_16P; USB_C_Receptacle_G-Switch_GT-USB-7010ASV; LCSC Part Number C2988369
Y1: X322516MOB4SI; LCSC Part Number C12668

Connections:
+3.3V: C1.1, C2.1, C3.1, C4.1, C5.1, C6.1, C7.1, C8.1, C11.1, C17.1, D39.2 (A), J5.1, R24.1, R33.1, SW2.2, U4.2 (VO), U6.1 (VBAT), U6.20 (VREF+), U6.21 (VDDA), U6.24 (VDD), U6.36 (VDD), U6.48 (VDD)
+5V: C10.1, F1.2, U2.5 (VBUS), U3.5 (VBUS), U4.3 (VI); also elsewhere on the board
/PWR_LED: D39.1 (K), R25.2
BOOT0: R3.1, SW2.1, U6.45 (PB8)
Col0: U6.32 (PA10); also elsewhere on the board
Col1: U6.29 (PB15); also elsewhere on the board
Col2: U6.28 (PB14); also elsewhere on the board
Col3: U6.27 (PB13); also elsewhere on the board
Col4: U6.26 (PB12); also elsewhere on the board
Col5: U6.13 (PA5); also elsewhere on the board
Col6: U6.8 (PA0); also elsewhere on the board
GND: C1.2, C2.2, C3.2, C4.2, C5.2, C6.2, C7.2, C8.2, C9.2, C10.2, C11.2, C15.2, C16.2, C17.2, J6.1, R1.2, R2.2, R4.1, R25.1, SW1.1, U2.2 (GND), U3.2 (GND), U4.1 (GND), U6.19 (VSSA), U6.23 (VSS), U6.35 (VSS), U6.47 (VSS), USB1.A1 (GND), USB1.A12 (GND), USB1.B1 (GND), USB1.B12 (GND), USB2.A1 (GND), USB2.A12 (GND), USB2.B1 (GND), USB2.B12 (GND), Y1.2 (GND_1), Y1.4 (GND_2); also elsewhere on the board
LED_MCU_SCL: R24.2, U6.31 (PA9); also elsewhere on the board
LED_MCU_SDA: R33.2, U6.30 (PA8); also elsewhere on the board
LED_MCU_SDB: U6.9 (PA1); also elsewhere on the board
NRST: C9.1, J2.4, SW1.2, U6.7 (PG10)
unnamed: R3.2, R4.2
unnamed: R1.1, USB1.A5 (CC1)
unnamed: R2.1, USB1.B5 (CC2)
PA15: J1.1, U6.39 (PA15)
PB4: J3.1, U6.41 (PB4)
PB9: J7.1, U6.16 (PB0)
RCC_OSC_IN: C15.1, U6.5 (PF0), Y1.1 (CRYSTAL_1)
RCC_OSC_OUT: C16.1, U6.6 (PF1), Y1.3 (CRYSTAL_2)
Row0: U6.10 (PA2); also elsewhere on the board
Row1: U6.11 (PA3); also elsewhere on the board
Row2: U6.4 (PC15); also elsewhere on the board
Row3: U6.3 (PC14); also elsewhere on the board
Row4: U6.14 (PA6); also elsewhere on the board
SYS_JTAG_SWCLK: J2.2, U6.38 (PA14)
SYS_JTAG_SWDIO: J2.1, U6.37 (PA13)
SYS_JTAG_TRACE: J2.3, U6.40 (PB3)
ThumbRow: U6.2 (PC13); also elsewhere on the board
USB_CONN_D+: U2.6 (I/O1), USB1.A6 (D+), USB1.B6 (D+)
USB_CONN_D-: U2.4 (I/O2), USB1.A7 (D-), USB1.B7 (D-)
USB_CONN_Tx+: U3.6 (I/O1), USB2.A6 (D+), USB2.B6 (D+)
USB_CONN_Tx-: U3.4 (I/O2), USB2.A7 (D-), USB2.B7 (D-)
USB_MCU_D+: U2.1 (I/O1), U6.34 (PA12)
USB_MCU_D-: U2.3 (I/O2), U6.33 (PA11)
USB_Tx+: U3.3 (I/O2), U6.43 (PB6)
USB_Tx-: U3.1 (I/O1), U6.44 (PB7)
VBUS: F1.1, USB1.A4 (VBUS), USB1.A9 (VBUS), USB1.B4 (VBUS), USB1.B9 (VBUS), USB2.A4 (VBUS), USB2.A9 (VBUS), USB2.B4 (VBUS), USB2.B9 (VBUS)

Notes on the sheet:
Place each cap close to a VDD and VSS pair.
Load Capacitance for link 1 & 2 are the same
Power and Ground Breakouts
Tx+=Tx Tx-=Rx
Must be 3.3V pull up 2k @ 1Mhz 4.7k @ 400kHz
Need to check to make sure the power caps are ceramic
Reset circuit (As on datasheet)
USB serial split connection
Bootloader circuit, pull down low (default) and push for high
Change address for RGB driver on right Change Rx Tx swapover to be straight on right
Enter boot by applying pattern 15: BOOT_LOCK(bit)=0, Boot0(pin) = 1, nBoot1(bit) = 1 and nBoot0_SW(bit) = 1 BOOT_LOCK(bit)=0, nBoot0(bit) = 0, nBoot1(bit) = 1 and nBoot0_SW(bit) = 0
Power and level converter to 3.3V
MCU Breakout Points
USB to PC Connector
ESD Protection for the two USB interfaces
HSE Oscillator Circuit for MCU
I2C for RGB Pull up resistors handled by RGB driver Pull SDB high to enable, Pull down (by driver side) to disable
Use two 5.1k resitors to get approx 10k. Already using 5.1k so same value
Serial Debug Connector
On the left side only swap Rx and Tx Left Rx - Right Tx Left Tx - Right Rx

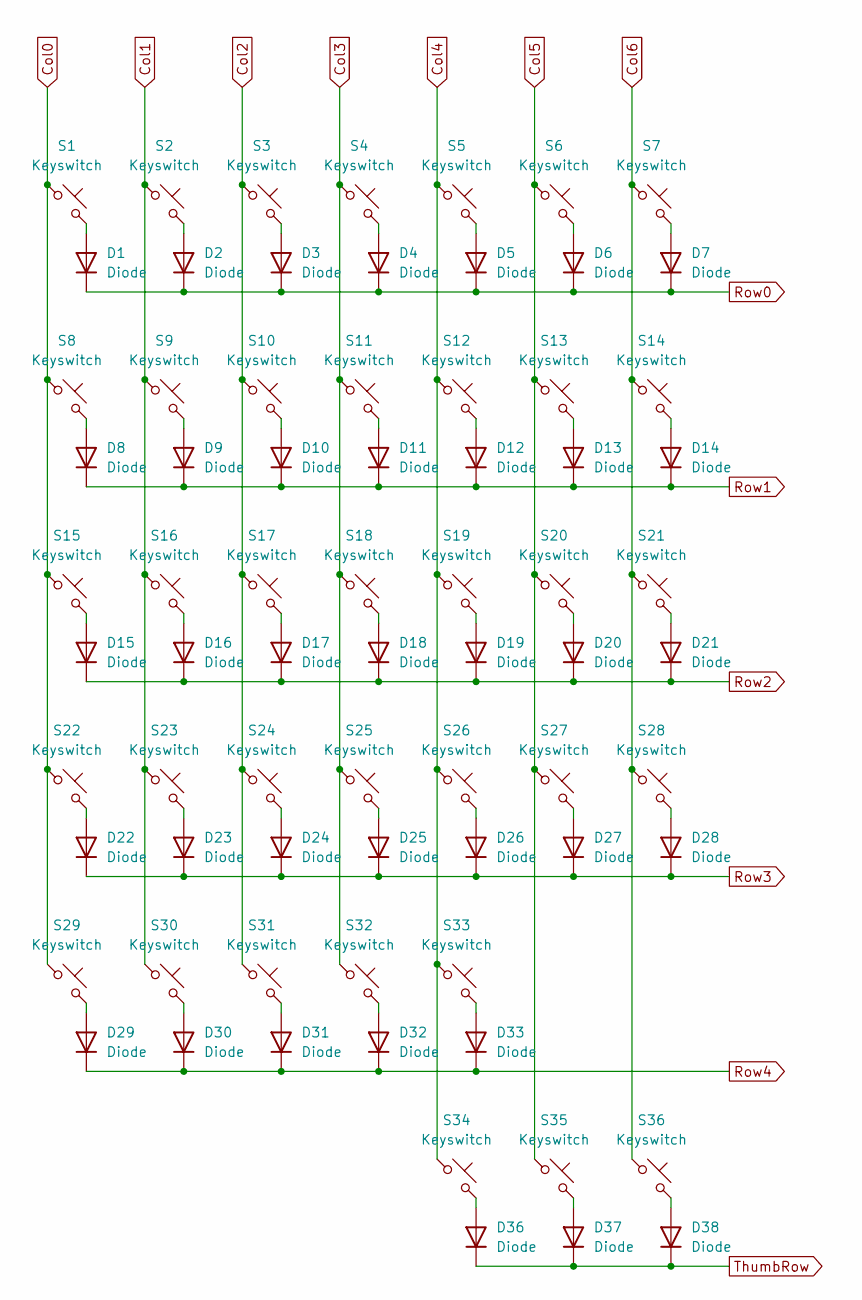
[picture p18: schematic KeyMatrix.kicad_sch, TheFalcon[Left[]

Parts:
D1, D2, D3, D4, D5, D6, D7, D8, D9, D10, D11, D12, D13, D14, D15, D16, D17, D18, D19, D20, D21, D22, D23, D24, D25, D26, D27, D28, D29, D30, D31, D32, D33, D36, D37, D38: Diode; D_SOD-123; LCSC Part Number C2099
S1, S2, S3, S4, S5, S6, S7, S8, S9, S10, S11, S12, S13, S14, S15, S16, S17, S18, S19, S20, S21, S22, S23, S24, S25, S26, S27, S28, S29, S30, S31, S32, S33, S34: Keyswitch; MX_KS33-Solderable-1U
S35, S36: Keyswitch; MX_KS33-Solderable-1.5U-Vertical

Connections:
Col0: S1.1, S8.1, S15.1, S22.1, S29.1; also elsewhere on the board
Col1: S2.1, S9.1, S16.1, S23.1, S30.1; also elsewhere on the board
Col2: S3.1, S10.1, S17.1, S24.1, S31.1; also elsewhere on the board
Col3: S4.1, S11.1, S18.1, S25.1, S32.1; also elsewhere on the board
Col4: S5.1, S12.1, S19.1, S26.1, S33.1, S34.1; also elsewhere on the board
Col5: S6.1, S13.1, S20.1, S27.1, S35.1; also elsewhere on the board
Col6: S7.1, S14.1, S21.1, S28.1, S36.1; also elsewhere on the board
unnamed: D1.2 (A), S1.2
unnamed: D2.2 (A), S2.2
unnamed: D3.2 (A), S3.2
unnamed: D4.2 (A), S4.2
unnamed: D5.2 (A), S5.2
unnamed: D6.2 (A), S6.2
unnamed: D7.2 (A), S7.2
unnamed: D8.2 (A), S8.2
unnamed: D9.2 (A), S9.2
unnamed: D10.2 (A), S10.2
unnamed: D11.2 (A), S11.2
unnamed: D12.2 (A), S12.2
unnamed: D13.2 (A), S13.2
unnamed: D14.2 (A), S14.2
unnamed: D15.2 (A), S15.2
unnamed: D16.2 (A), S16.2
unnamed: D17.2 (A), S17.2
unnamed: D18.2 (A), S18.2
unnamed: D19.2 (A), S19.2
unnamed: D20.2 (A), S20.2
unnamed: D21.2 (A), S21.2
unnamed: D22.2 (A), S22.2
unnamed: D23.2 (A), S23.2
unnamed: D24.2 (A), S24.2
unnamed: D25.2 (A), S25.2
unnamed: D26.2 (A), S26.2
unnamed: D27.2 (A), S27.2
unnamed: D28.2 (A), S28.2
unnamed: D29.2 (A), S29.2
unnamed: D30.2 (A), S30.2
unnamed: D31.2 (A), S31.2
unnamed: D32.2 (A), S32.2
unnamed: D33.2 (A), S33.2
unnamed: D36.2 (A), S34.2
unnamed: D37.2 (A), S35.2
unnamed: D38.2 (A), S36.2
Row0: D1.1 (K), D2.1 (K), D3.1 (K), D4.1 (K), D5.1 (K), D6.1 (K), D7.1 (K); also elsewhere on the board
Row1: D8.1 (K), D9.1 (K), D10.1 (K), D11.1 (K), D12.1 (K), D13.1 (K), D14.1 (K); also elsewhere on the board
Row2: D15.1 (K), D16.1 (K), D17.1 (K), D18.1 (K), D19.1 (K), D20.1 (K), D21.1 (K); also elsewhere on the board
Row3: D22.1 (K), D23.1 (K), D24.1 (K), D25.1 (K), D26.1 (K), D27.1 (K), D28.1 (K); also elsewhere on the board
Row4: D29.1 (K), D30.1 (K), D31.1 (K), D32.1 (K), D33.1 (K); also elsewhere on the board
ThumbRow: D36.1 (K), D37.1 (K), D38.1 (K); also elsewhere on the board

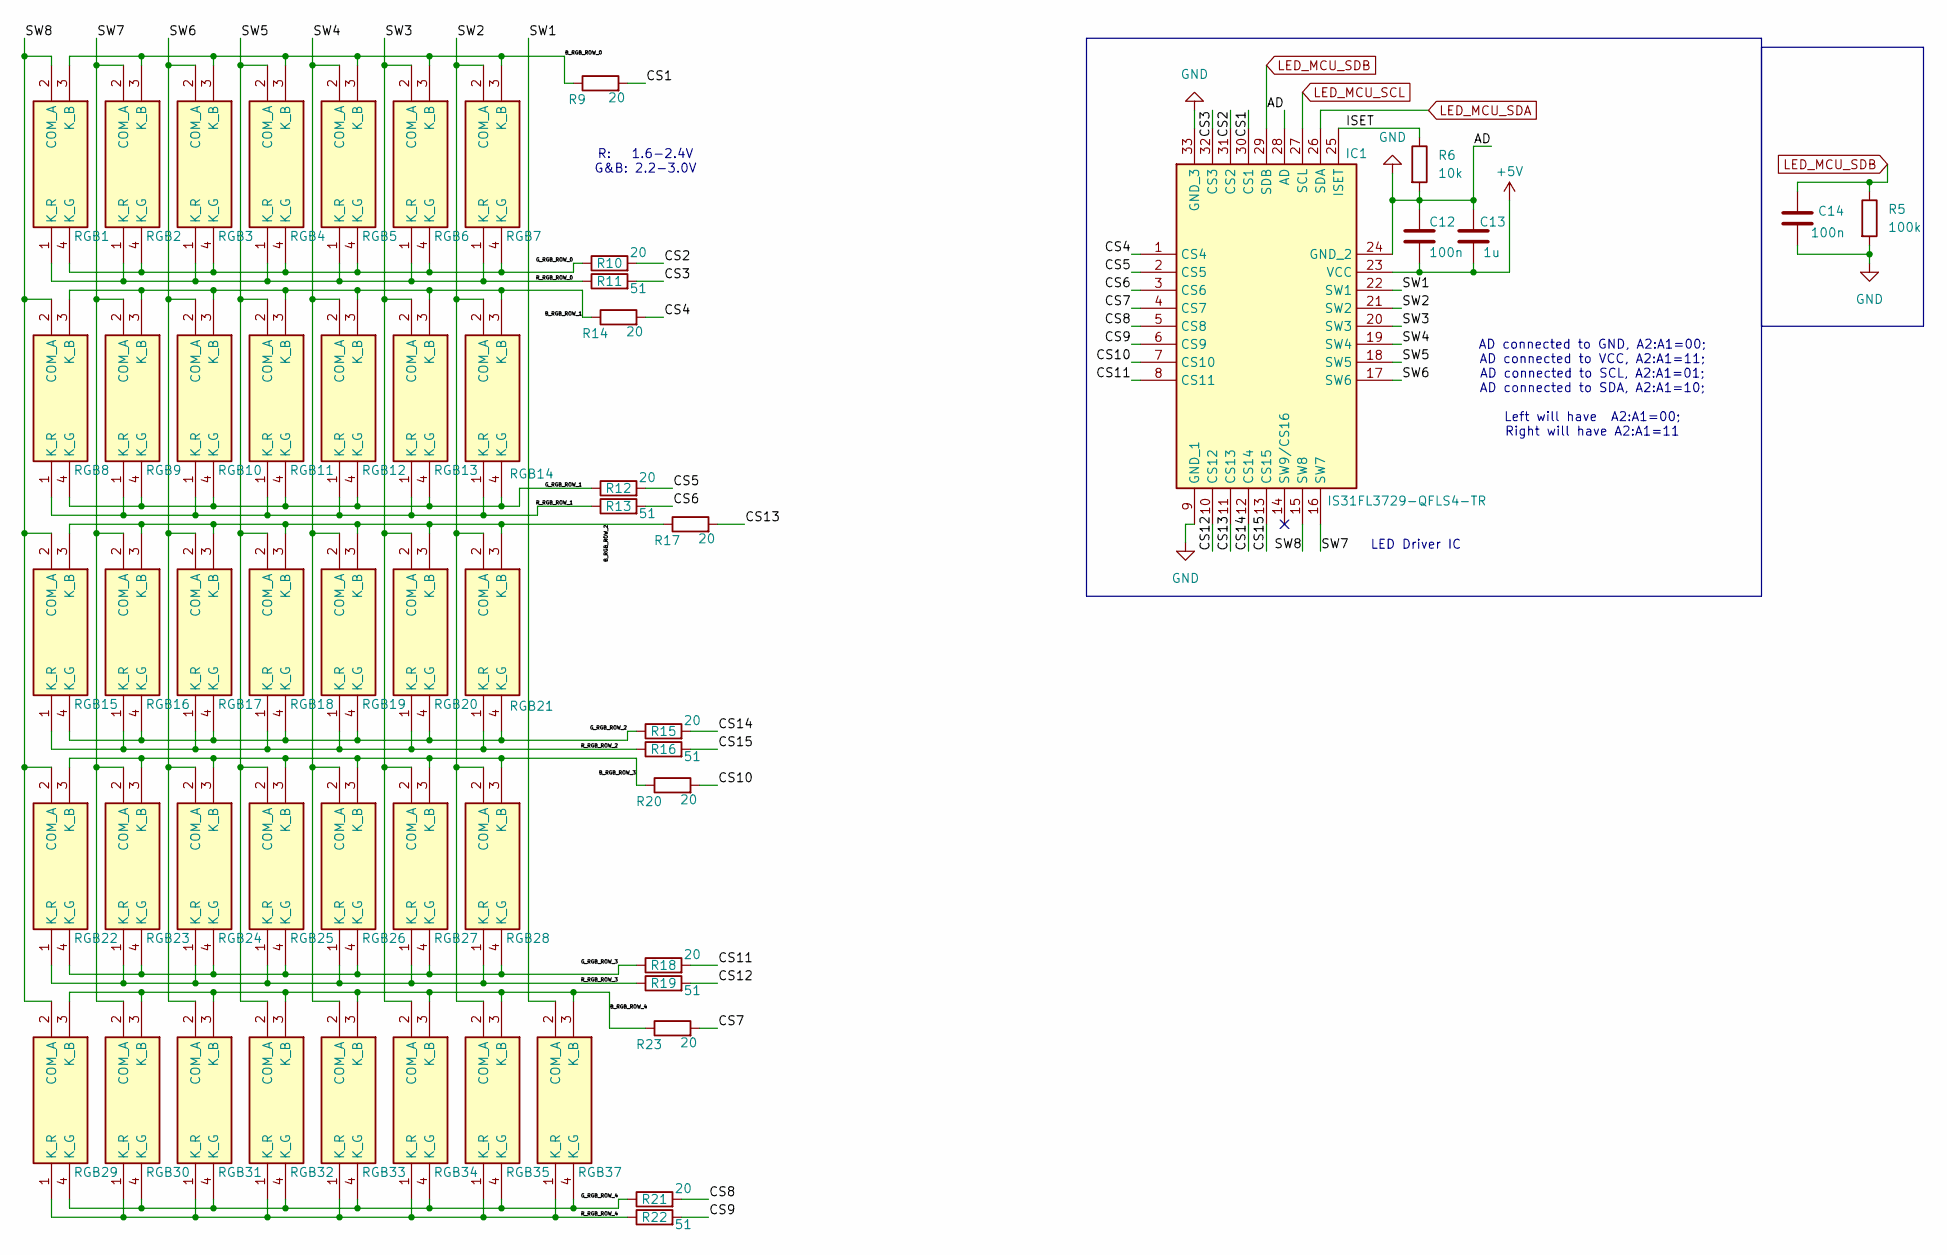
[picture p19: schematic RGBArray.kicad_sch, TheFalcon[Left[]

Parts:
C12, C14: 100n; C_0402_1005Metric; LCSC Part Number C1525
C13: 1u; C_0603_1608Metric; LCSC Part Number C1592
IC1: IS31FL3729-QFLS4-TR; QFN40P400X400X80-33N-D; LCSC Part Number C2940549
R5: 100k; R_0603_1608Metric; LCSC Part Number C14675
R6: 10k; R_0603_1608Metric; LCSC Part Number C15401
R9, R10, R12, R14, R15, R17, R18, R20, R21, R23: 20; R_0603_1608Metric; LCSC Part Number C22950
R11, R13, R16, R19, R22: 51; R_0603_1608Metric; LCSC Part Number C17738
RGB1, RGB2, RGB3, RGB4, RGB5, RGB6, RGB7, RGB8, RGB9, RGB10, RGB11, RGB12, RGB13, RGB14, RGB15, RGB16, RGB17, RGB18, RGB19, RGB20, RGB21, RGB22, RGB23, RGB24, RGB25, RGB26, RGB27, RGB28, RGB29, RGB30, RGB31, RGB32, RGB33, RGB34, RGB35, RGB37: T36K3BGR-05D000121U1930; T36K3BGR05D000121U1930_MODEL_INVERTED

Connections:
+5V: C12.2, C13.2, IC1.23 (VCC); also elsewhere on the board
/RGB Array/B_RGB_ROW_0: R9.1, RGB1.3 (K_B), RGB2.3 (K_B), RGB3.3 (K_B), RGB4.3 (K_B), RGB5.3 (K_B), RGB6.3 (K_B), RGB7.3 (K_B)
/RGB Array/B_RGB_ROW_1: R14.1, RGB8.3 (K_B), RGB9.3 (K_B), RGB10.3 (K_B), RGB11.3 (K_B), RGB12.3 (K_B), RGB13.3 (K_B), RGB14.3 (K_B)
/RGB Array/B_RGB_ROW_2: R17.1, RGB15.3 (K_B), RGB16.3 (K_B), RGB17.3 (K_B), RGB18.3 (K_B), RGB19.3 (K_B), RGB20.3 (K_B), RGB21.3 (K_B)
/RGB Array/B_RGB_ROW_3: R20.1, RGB22.3 (K_B), RGB23.3 (K_B), RGB24.3 (K_B), RGB25.3 (K_B), RGB26.3 (K_B), RGB27.3 (K_B), RGB28.3 (K_B)
/RGB Array/B_RGB_ROW_4: R23.1, RGB29.3 (K_B), RGB30.3 (K_B), RGB31.3 (K_B), RGB32.3 (K_B), RGB33.3 (K_B), RGB34.3 (K_B), RGB35.3 (K_B), RGB37.3 (K_B)
/RGB Array/CS1: IC1.30 (CS1), R9.2
/RGB Array/CS2: IC1.31 (CS2), R10.2
/RGB Array/CS3: IC1.32 (CS3), R11.2
/RGB Array/CS4: IC1.1 (CS4), R14.2
/RGB Array/CS5: IC1.2 (CS5), R12.2
/RGB Array/CS6: IC1.3 (CS6), R13.2
/RGB Array/CS7: IC1.4 (CS7), R23.2
/RGB Array/CS8: IC1.5 (CS8), R21.2
/RGB Array/CS9: IC1.6 (CS9), R22.2
/RGB Array/CS10: IC1.7 (CS10), R20.2
/RGB Array/CS11: IC1.8 (CS11), R18.2
/RGB Array/CS12: IC1.10 (CS12), R19.2
/RGB Array/CS13: IC1.11 (CS13), R17.2
/RGB Array/CS14: IC1.12 (CS14), R15.2
/RGB Array/CS15: IC1.13 (CS15), R16.2
/RGB Array/G_RGB_ROW_0: R10.1, RGB1.4 (K_G), RGB2.4 (K_G), RGB3.4 (K_G), RGB4.4 (K_G), RGB5.4 (K_G), RGB6.4 (K_G), RGB7.4 (K_G)
/RGB Array/G_RGB_ROW_1: R12.1, RGB8.4 (K_G), RGB9.4 (K_G), RGB10.4 (K_G), RGB11.4 (K_G), RGB12.4 (K_G), RGB13.4 (K_G), RGB14.4 (K_G)
/RGB Array/G_RGB_ROW_2: R15.1, RGB15.4 (K_G), RGB16.4 (K_G), RGB17.4 (K_G), RGB18.4 (K_G), RGB19.4 (K_G), RGB20.4 (K_G), RGB21.4 (K_G)
/RGB Array/G_RGB_ROW_3: R18.1, RGB22.4 (K_G), RGB23.4 (K_G), RGB24.4 (K_G), RGB25.4 (K_G), RGB26.4 (K_G), RGB27.4 (K_G), RGB28.4 (K_G)
/RGB Array/G_RGB_ROW_4: R21.1, RGB29.4 (K_G), RGB30.4 (K_G), RGB31.4 (K_G), RGB32.4 (K_G), RGB33.4 (K_G), RGB34.4 (K_G), RGB35.4 (K_G), RGB37.4 (K_G)
/RGB Array/ISET: IC1.25 (ISET), R6.1
/RGB Array/R_RGB_ROW_0: R11.1, RGB1.1 (K_R), RGB2.1 (K_R), RGB3.1 (K_R), RGB4.1 (K_R), RGB5.1 (K_R), RGB6.1 (K_R), RGB7.1 (K_R)
/RGB Array/R_RGB_ROW_1: R13.1, RGB8.1 (K_R), RGB9.1 (K_R), RGB10.1 (K_R), RGB11.1 (K_R), RGB12.1 (K_R), RGB13.1 (K_R), RGB14.1 (K_R)
/RGB Array/R_RGB_ROW_2: R16.1, RGB15.1 (K_R), RGB16.1 (K_R), RGB17.1 (K_R), RGB18.1 (K_R), RGB19.1 (K_R), RGB20.1 (K_R), RGB21.1 (K_R)
/RGB Array/R_RGB_ROW_3: R19.1, RGB22.1 (K_R), RGB23.1 (K_R), RGB24.1 (K_R), RGB25.1 (K_R), RGB26.1 (K_R), RGB27.1 (K_R), RGB28.1 (K_R)
/RGB Array/R_RGB_ROW_4: R22.1, RGB29.1 (K_R), RGB30.1 (K_R), RGB31.1 (K_R), RGB32.1 (K_R), RGB33.1 (K_R), RGB34.1 (K_R), RGB35.1 (K_R), RGB37.1 (K_R)
/RGB Array/SW1: IC1.22 (SW1), RGB37.2 (COM_A)
/RGB Array/SW2: IC1.21 (SW2), RGB7.2 (COM_A), RGB14.2 (COM_A), RGB21.2 (COM_A), RGB28.2 (COM_A), RGB35.2 (COM_A)
/RGB Array/SW3: IC1.20 (SW3), RGB6.2 (COM_A), RGB13.2 (COM_A), RGB20.2 (COM_A), RGB27.2 (COM_A), RGB34.2 (COM_A)
/RGB Array/SW4: IC1.19 (SW4), RGB5.2 (COM_A), RGB12.2 (COM_A), RGB19.2 (COM_A), RGB26.2 (COM_A), RGB33.2 (COM_A)
/RGB Array/SW5: IC1.18 (SW5), RGB4.2 (COM_A), RGB11.2 (COM_A), RGB18.2 (COM_A), RGB25.2 (COM_A), RGB32.2 (COM_A)
/RGB Array/SW6: IC1.17 (SW6), RGB3.2 (COM_A), RGB10.2 (COM_A), RGB17.2 (COM_A), RGB24.2 (COM_A), RGB31.2 (COM_A)
/RGB Array/SW7: IC1.16 (SW7), RGB2.2 (COM_A), RGB9.2 (COM_A), RGB16.2 (COM_A), RGB23.2 (COM_A), RGB30.2 (COM_A)
/RGB Array/SW8: IC1.15 (SW8), RGB1.2 (COM_A), RGB8.2 (COM_A), RGB15.2 (COM_A), RGB22.2 (COM_A), RGB29.2 (COM_A)
GND: C12.1, C13.1, C14.2, IC1.9 (GND_1), IC1.24 (GND_2), IC1.28 (AD), IC1.33 (GND_3), R5.2, R6.2; also elsewhere on the board
LED_MCU_SCL: IC1.27 (SCL); also elsewhere on the board
LED_MCU_SDA: IC1.26 (SDA); also elsewhere on the board
LED_MCU_SDB: C14.1, IC1.29 (SDB), R5.1; also elsewhere on the board

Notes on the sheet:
AD connected to GND, A2:A1=00; AD connected to VCC, A2:A1=11; AD connected to SCL, A2:A1=01; AD connected to SDA, A2:A1=10; Left will have A2:A1=00; Right will have A2:A1=11
LED Driver IC
R: 1.6-2.4V G&B: 2.2-3.0V

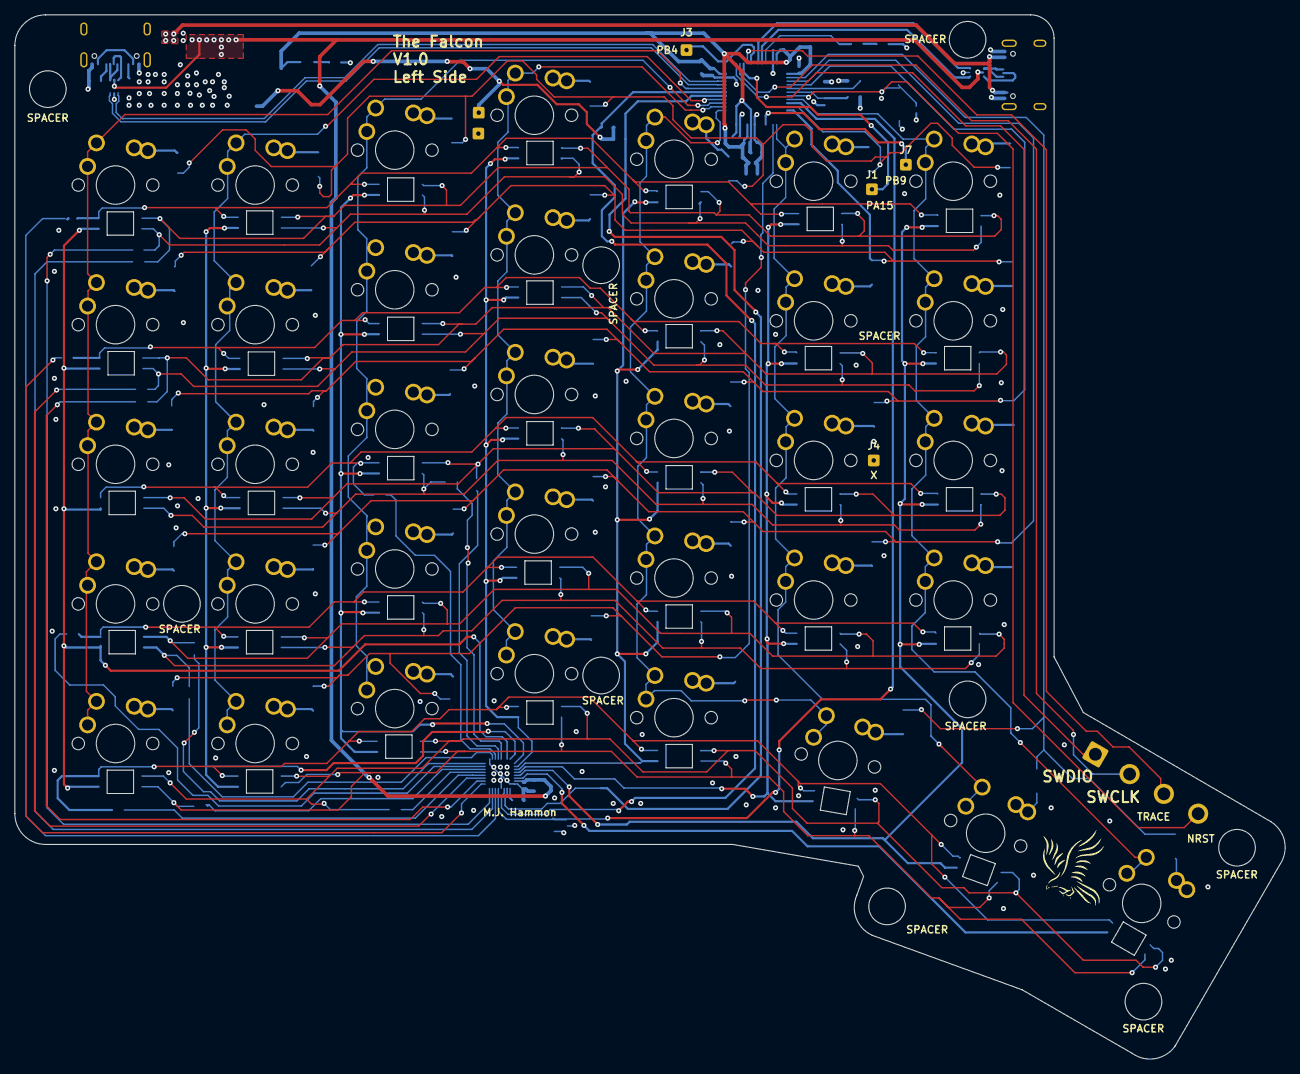
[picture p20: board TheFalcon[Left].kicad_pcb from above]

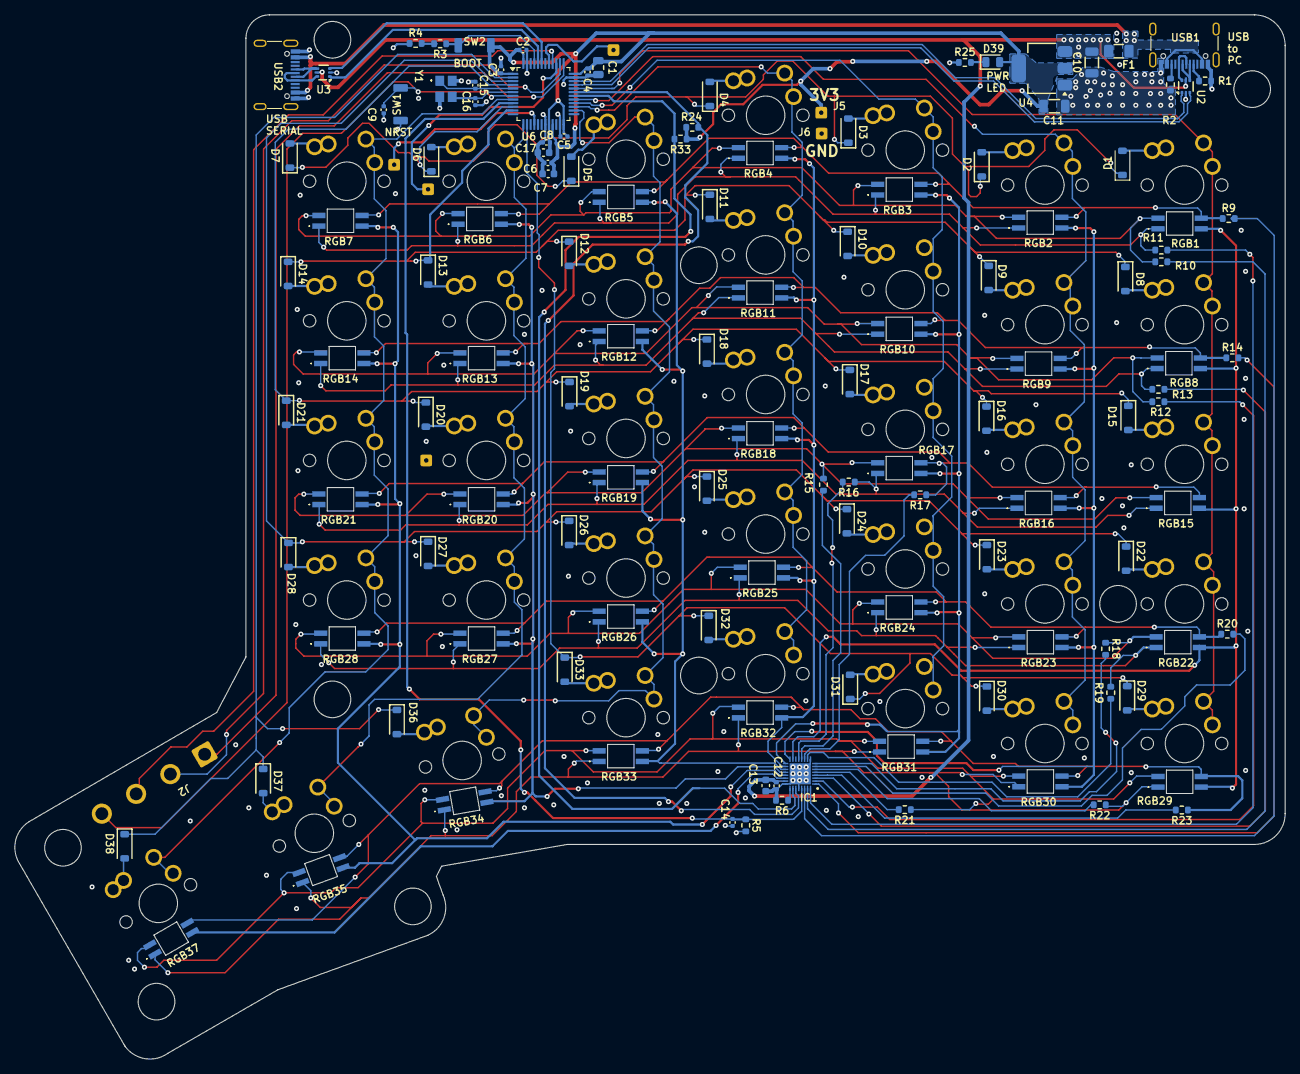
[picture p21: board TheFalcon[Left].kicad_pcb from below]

Board: 4 copper layers, 173.3 x 142.5 mm, 168 parts (92 on the bottom side), 117 nets.

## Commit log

2025-07-12 Saving before I go crazy on PCB
    [RGBArray.kicad_sch, TheFalcon[Left].kicad_sch]
2025-07-14 TwoUSBs on Top
    [TheFalcon[Left].kicad_pcb]
2025-07-19 Cleaning up
    I have all connections, just cleaning up
    [RGBArray.kicad_sch, TheFalcon[Left].kicad_pcb, TheFalcon[Left].kicad_sch]
2025-07-19 Save
    Done left side, going to start right side now
    [TheFalcon[Left].kicad_pcb, bom.csv, designators.csv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]
2025-07-21 Right Side Done
    Need to check but right side looks good
    [RGBArray.kicad_sch, TheFalcon[Right].kicad_pcb, TheFalcon[Right].kicad_sch]
2025-07-29 Going to add screw holes
2025-07-29 Saving
    Added Edge but about to get rid of screws on edge
    [BottomPlate.SLDPRT, SwitchLayer.SLDPRT]
2025-07-30 Save
    Case done for left and right side
    [BottomPlate.SLDPRT, SwitchLayer.SLDPRT]
2025-07-31 Save
    Checked right PCB and hole to track spacing for left. Will do check for left pcb tomorrow
    [KeyMatrix.kicad_sch, TheFalcon[Left].kicad_pcb, TheFalcon[Right].kicad_pcb]
2025-08-01 Save
    Done checking left and right PCB and case.
    [TheFalcon[Left].kicad_pcb, TheFalcon[Right].kicad_pcb]
2025-08-03 Files ready for production
    Going to panelise seperate files to reduce PCBA cost
    [KeyMatrix.kicad_sch, PartsList.xlsx, RGBArray.kicad_sch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]
2025-08-04 Adding Panels to PCB
    [KeyMatrix.kicad_sch, KeyMatrix_Right.kicad_sch, PartsList.xlsx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]
2025-08-06 Save
    Trying a different panel
    [RGBArray.kicad_sch, RGBArray_Right.kicad_sch, TheFalcon_Left.kicad_sch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]
2026-08-26 Working on updating GH
    Just added some cleanup .gitignores as I want to cleanup the repo
    [BottomPlate_Right.SLDPRT, LeftSideCase.SLDASM, RightSideCase.SLDASM]
2026-08-26 Save
    Cleaned up the files and want to do the writeup now.
    [BottomPlate.STEP, BottomPlate_Left.SLDPRT, BottomPlate_Left.STEP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]
2026-08-26 Revise README to introduce Falcon keyboard project
    Expanded the README to detail the Falcon keyboard project, including features, PCB design, and case information.
2026-08-26 Update README with parts list and BOM details
    Added sections for parts list and bill of materials with sourcing information.
2026-08-26 Added BOM and parts list
    [bom.xlsx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]
